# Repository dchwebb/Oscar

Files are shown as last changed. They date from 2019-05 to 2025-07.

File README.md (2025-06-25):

# Oscar

Overview
--------

Oscar is a three channel oscilloscope, tuner, spectrum analyser and MIDI event viewer designed for use in a Eurorack modular synthesiser.

- [Manual](Oscar_Manual.md)

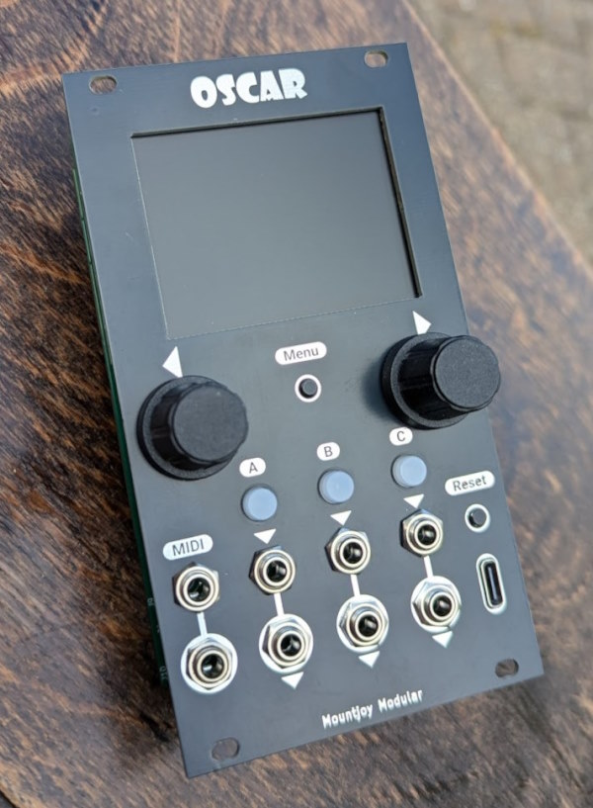
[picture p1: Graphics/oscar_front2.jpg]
Oscar icon


Version 3 changes: 
- Optimised for DIY building
    - [Build Guide](Oscar_Build_Guide.md)
    - [Bill of Materials](BOM.md)
- Illuminated buttons for quick channel selection
- USB input for firmware updates and USB MIDI analysis
- An opto-coupler and passive mult on the serial MIDI input
- Dedicated Menu button

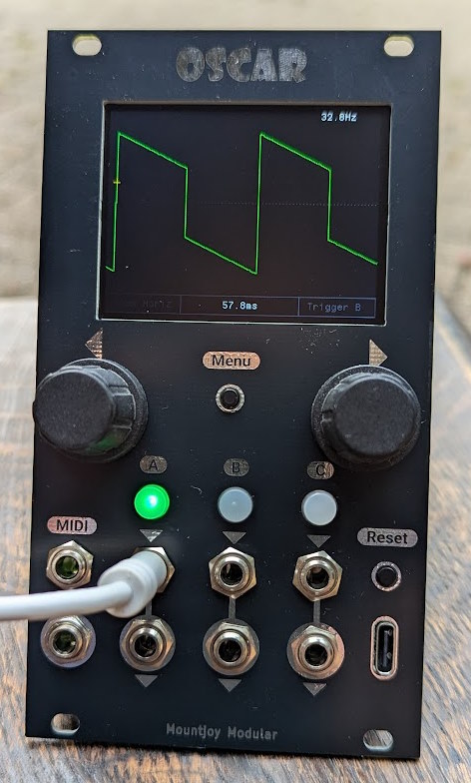
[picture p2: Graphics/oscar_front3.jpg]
Oscar icon


Functional Overview
-------------------

See [Manual](Oscar_Manual.md) for more details.

- The oscilloscope can display up to three channels at once, either in separate lanes or overlaid. Horizontal and vertical zoom are available and a trigger with adjustable x/y can be applied to any channel.

- The tuner function allows for fast and accurate tuning of audio rate signals.

- The spectrum analyser is used to show the frequency components of any signal. The frequencies of the principal harmonics are shown both graphically and numerically. An autotune function dynamically adjusts the sample rate to lock on the fundamental frequency of the signal. This gives an extremely clear view of the frequency spectrum whilst being fast enough for real-time use.

- The waterfall plot shows the frequency spectrum over time in a 3 dimensional view.

- The MIDI event viewer displays the MIDI channel, note on/off status, pitchbends, control changes and aftertouch. Clock speed is indicated with a flashing dot. 

Technical
---------

Oscar uses an SMT32F446 microcontroller to capture incoming signals with the internal ADC and display the results on a 320x240 LCD display via SPI. Code is written in C++ 20 using the STM32CubeIDE Eclipse-based IDE. Hardware interfacing is carried out through custom code (ie no STM HAL libraries).

- [Schematics](Hardware_v3/Oscar_Components.pdf)

The microcontroller is clocked at 180MHz via an external 8MHz crystal oscillator. The analog inputs are scaled with an MCP6004 op-amp and the mult outputs buffered with a TL074 op-amp. The internal UART is used to capture serial MIDI data for display via a H11L1 optocoupler (to reduce the risk of ground hum).

The display is a 320x240 TFT LCD controlled with an ILI9341 driver. Screen refreshes are sent using SPI via DMA from the microcontroller. A USB C socket functions in USB 2.0 mode with an RCLAMP0502B providing ESD protection.

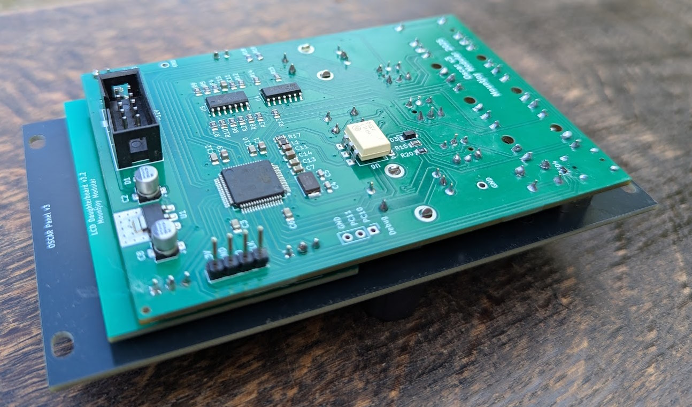
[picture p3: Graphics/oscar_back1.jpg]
Oscar icon


Analog signal capture is carried out via the internal 12 bit ADCs. Capture is controlled by a timer that is adjusted to the desired horizontal display frequency in oscilloscope mode. In Spectrum Analyser mode the autotune function dynamically alters the sampling rate to attempt to capture an integer multiple of the fundamental frequency of the incoming signal. This is done by inspecting the side-lobes of the FFT and altering the sampling rate to minimise the offset.

The tuner mode uses an overlapping FFT technique to increase accuracy. Using this mechanism samples 1 to 1024 are placed in one buffer and samples 512 to 1536 are placed in a second buffer. FFTs are carried out on each buffer and then the phase offset between the fundamental is measured. This can then be used to calculate the pitch with much enhanced accuracy for the additional processing time.

### Power Supply

The Eurorack +/-12V rails have reverse polarity protection and filtering. The 3.3V MCU and DAC digital power supplies are provided by an LT1117-3.3 linear regulator. A common digital/analog ground plane is used.

- +12V Current Draw: 151mA
- -12V Current Draw: 6mA

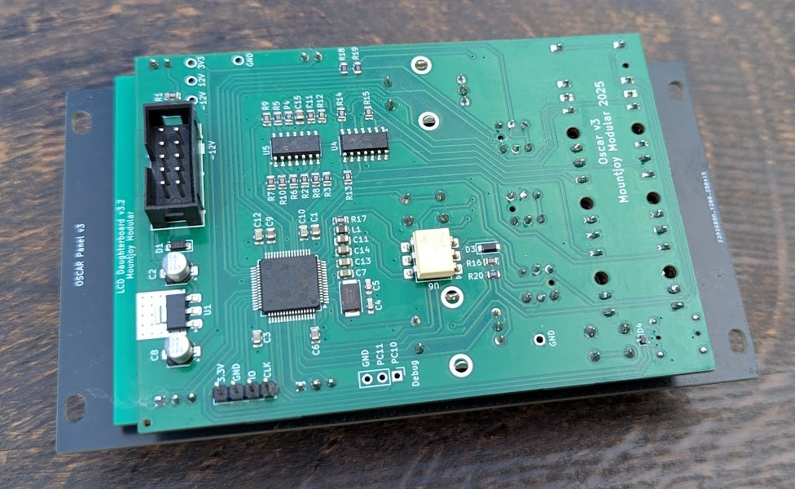
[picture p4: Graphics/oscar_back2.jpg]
Oscar icon


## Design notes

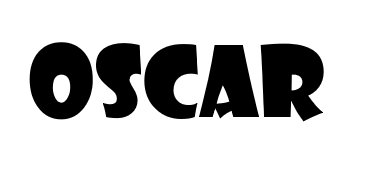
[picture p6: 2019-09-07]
Hardware_v3/Graphics/Oscar showcard gothic.png

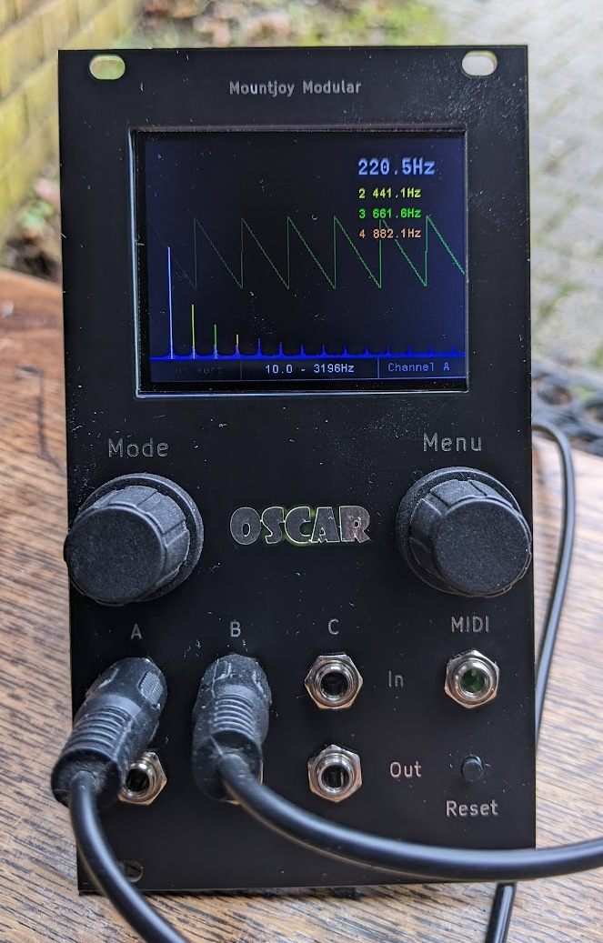
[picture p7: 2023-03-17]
Graphics/Spectrum.jpg

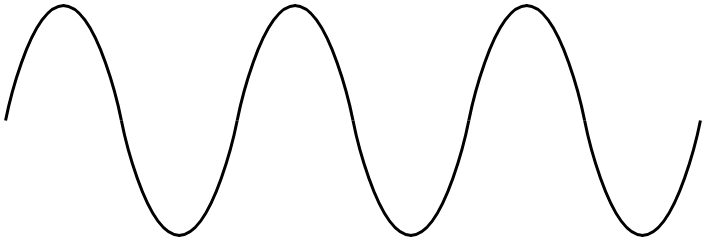
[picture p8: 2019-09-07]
Hardware_v3/Graphics/sine.png

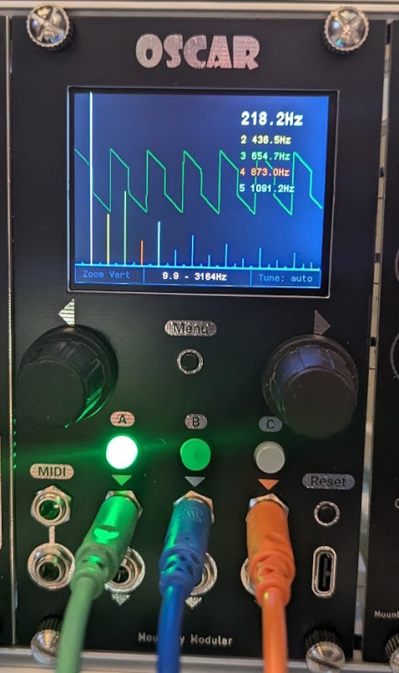
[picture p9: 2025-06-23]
Graphics/spectrum_v3.jpg

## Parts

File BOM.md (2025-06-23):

# Oscar v3 BOM

## Screen

- [2.4 inch TFT HD Color LCD Screen 2.8-3.3V 240x320 4-wire SPI interface ILI9341](https://www.ebay.co.uk/itm/394725476377)
- Various lengths of 2.54mm pin headers

## Generic Parts (optional if using JLC assembly)

|Value |Designator |Footprint |JLC |
|---|---|---|---|
|8MHz |Y1 |Crystal 5032 2 Pin 5.0x3.2mm |C115962 |
|STM32F446RETx|U3 |LQFP-64_10x10mm_P0.5mm |C69336  |
|H11L1 |U6 |H11L1 Optocoupler |C20082  |
|RCLAMP0502B  |D4 |SOT-416 ESD Protection for USB |C5370962|
|LT1117-3.3 |U1 |SOT-223-3 TabPin2 Linear Regulator |C6186 |
|TL074 |U4 |SOIC-14_3.9x8.7mm_P1.27mm OpAmp |C107644 |
|MCP6004 |U5 |SOIC-14_3.9x8.7mm_P1.27mm OpAmp |C7378 |
|1N4148W |D3 |D_SOD-123 Diode |C81598  |
|1N5819 |D1,D2 |D_SOD-123 Diode |C8598 |
|Ferrite Bead |L1 |0805 300mΩ 600Ω@100MHz Ferrite Bead |C1017 |
|22uF 16V |C2,C8 |Electrolytic Capacitor 4 x 5.8mm |C134793 |
|4.7uF |C1,C11,C15,C9 |0805 Capacitor |C1779 |
|1uF |C14 |0805 Capacitor |C28323  |
|100nF |C10,C12,C13,C3,C6,C7|0805 Capacitor |C49678  |
|30pF |C4,C5 |0603 Capacitor |C1658 |
|100 |R13,R14,R15 |0805 1% Resistor |C17408  |
|150 |R1 |0805 1% Resistor |C17471  |
|220 |R16 |0805 1% Resistor |C17557  |
|470 |R17 |0805 1% Resistor |C17710  |
|1.5k |R18,R19,R20 |0805 1% Resistor |C4310 |
|10k |R11,R12 |0805 1% Resistor |C17414  |
|15k |R10,R8,R9 |0805 1% Resistor |C17475  |
|100k |R2,R3,R4,R5,R6,R7 |0805 1% Resistor |C149504 |

## Digikey/Mouser Components

|Comment |Designator |Footprint |Digikey |Mouser |
|---|---|---|---|---|
|Menu Button  |SW2 |Tactile Switch SKHHDTA010 |4809-SKHHDTA010-ND |688-SKHHDT |
|Reset Button |SW1 |Tactile Switch SKHHDTA010 |4809-SKHHDTA010-ND |688-SKHHDT |
|Right Encoder|SW4 |Rotary Encoder PEC11R-4220F-S0024 |PEC11R-4220F-S0024-ND |652-PEC11R-4220F-S24|
|Left Encoder |SW3 |Rotary Encoder PEC11R-4220F-S0024 |PEC11R-4220F-S0024-ND |652-PEC11R-4220F-S24|
|USB C Socket |J11 |Amphenol 12401951E412A |664-12401951E412ATR-ND|523-12401951E412A |
|Eurorack 10 pin power|J2 |Eurorack 10 pin shrouded header |SAM10831-ND |200-TST10501TD |

## Thonk Components

|Comment |Designator |Footprint |Thonk |
|---|---|---|---|
|ChA Btn |BTN1 |Low Profile LED Button |[Low-Profile LED Button - GREEN](https://www.thonk.co.uk/shop/low-profile-led-buttons/)|
|ChB Btn |BTN2 |Low Profile LED Button |[Low-Profile LED Button - BLUE](https://www.thonk.co.uk/shop/low-profile-led-buttons/)|
|ChC Btn |BTN3 |Low Profile LED Button |[Low-Profile LED Button - ORANGE](https://www.thonk.co.uk/shop/low-profile-led-buttons/)|
|ChannelA In  |J4 |THONKICONN hole |[Thonkiconn Mono 3.5mm Audio Jacks (WQP518MA)](https://www.thonk.co.uk/shop/thonkiconn/)|
|ChannelB In  |J5 |THONKICONN hole |[Thonkiconn Mono 3.5mm Audio Jacks (WQP518MA)](https://www.thonk.co.uk/shop/thonkiconn/)|
|ChA Buff Out |J7 |THONKICONN hole |[Thonkiconn Mono 3.5mm Audio Jacks (WQP518MA)](https://www.thonk.co.uk/shop/thonkiconn/)|
|ChB Buff Out |J8 |THONKICONN hole |[Thonkiconn Mono 3.5mm Audio Jacks (WQP518MA)](https://www.thonk.co.uk/shop/thonkiconn/)|
|ChC Buff Out |J6 |THONKICONN hole |[Thonkiconn Mono 3.5mm Audio Jacks (WQP518MA)](https://www.thonk.co.uk/shop/thonkiconn/)|
|ChannelC In  |J3 |THONKICONN hole |[Thonkiconn Mono 3.5mm Audio Jacks (WQP518MA)](https://www.thonk.co.uk/shop/thonkiconn/)|
|MIDI IN |J9 |Thonkiconn Stereo-PJ366ST |[Green Thonkiconn Stereo 3.5mm Audio Jacks (PJ366ST)](https://www.thonk.co.uk/shop/thonkiconn/)|
|MIDI THROUGH |J10 |Thonkiconn Stereo-PJ366ST |[Green Thonkiconn Stereo 3.5mm Audio Jacks (PJ366ST)](https://www.thonk.co.uk/shop/thonkiconn/)|

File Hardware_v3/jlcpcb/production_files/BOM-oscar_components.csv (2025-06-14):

Comment | Designator | Footprint | LCSC
L | L1 | R_0805_2012Metric | C1017
TL074 | U4 | SOIC-14_3.9x8.7mm_P1.27mm | C107644
8MHz | Y1 | Crystal_SMD_5032-2Pin_5.0x3.2mm_Large_Pads | C115962
22uF | C2,C8 | CP_Elec_4x5.8 | C134793
100k | R2,R3,R4,R5,R6,R7 | R_0805_2012Metric | C149504
30pF | C4,C5 | C_0603_1608Metric_Pad1.08x0.95mm_HandSolder | C1658
100 | R13,R14,R15 | R_0805_2012Metric | C17408
10k | R11,R12 | R_0805_2012Metric | C17414
150 | R1 | R_0805_2012Metric | C17471
15k | R10,R8,R9 | R_0805_2012Metric | C17475
220 | R16 | R_0805_2012Metric | C17557
470 | R17 | R_0805_2012Metric | C17710
4.7uF | C1,C11,C15,C9 | C_0805_2012Metric | C1779
H11L1 | U6 | H11L1 | C20082
1uF | C14 | C_0805_2012Metric | C28323
1.5k | R18,R19,R20 | R_0805_2012Metric | C4310
100nF | C10,C12,C13,C3,C6,C7 | C_0805_2012Metric | C49678
RCLAMP0502B | D4 | SOT-416 | C5370962
LT1117-3.3 | U1 | SOT-223-3_TabPin2 | C6186
STM32F446RETx | U3 | LQFP-64_10x10mm_P0.5mm | C69336
MCP6004 | U5 | SOIC-14_3.9x8.7mm_P1.27mm | C7378
1N4148W | D3 | D_SOD-123 | C81598
1N5819 | D1,D2 | D_SOD-123 | C8598
Menu_Button | SW2 | SW_PUSH_6mm_aligned
ILI9341_SPI_Daughterboard | U2 | ILI9341_SPI_daughterboard_v2
ChannelA_In | J4 | THONKICONN_hole
ChannelB_In | J5 | THONKICONN_hole
ChA_Buff_Out | J7 | THONKICONN_hole
ChB_Buff_Out | J8 | THONKICONN_hole
ChC_Buff_Out | J6 | THONKICONN_hole
Right_Encoder | SW4 | Encoder
Left_Encoder | SW3 | Encoder
ChannelC_In | J3 | THONKICONN_hole
MIDI_IN | J9 | Thonkiconn_Stereo-PJ366ST
Reset_Button | SW1 | SW_PUSH_6mm_aligned
ChB_Btn | BTN2 | Low_Profile_LED_Button
ChC_Btn | BTN3 | Low_Profile_LED_Button
ChA_Btn | BTN1 | Low_Profile_LED_Button
USB_C_Receptacle | J11 | USB_C_Receptacle_Amphenol_12401951E412A
MIDI_THROUGH | J10 | Thonkiconn_Stereo-PJ366ST

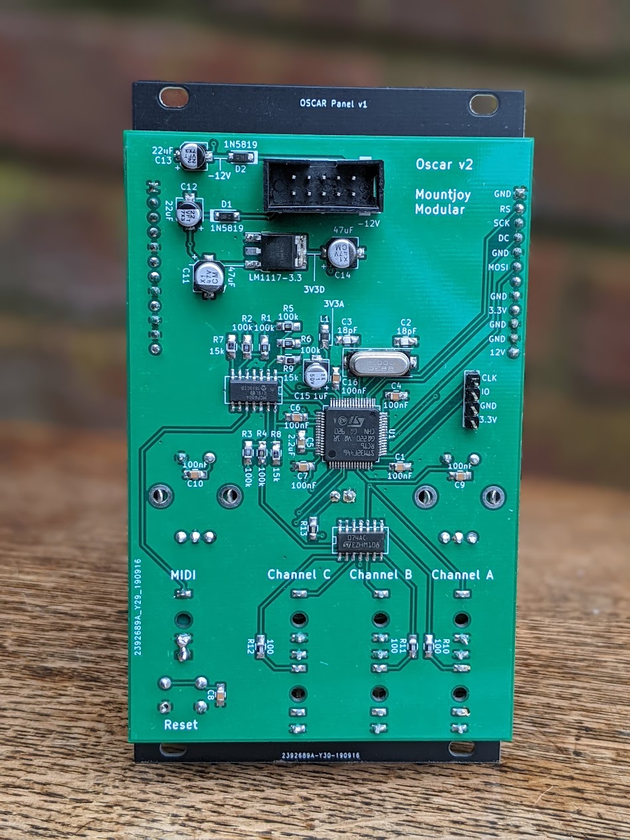
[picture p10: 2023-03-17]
Graphics/Components.jpg

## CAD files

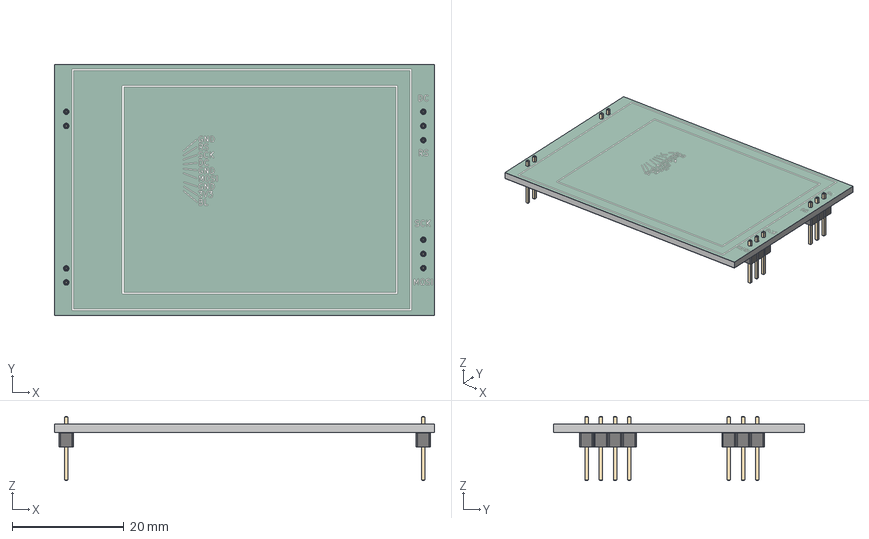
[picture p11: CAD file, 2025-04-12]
Hardware_v3/lcd_Daughterboard.step
68.0 x 45.0 x 11.5 mm
PinHeader_1x02_P2.54mm_Vertical x 2
PinHeader_1x03_P2.54mm_Vertical x 2
lcd_Daughterboard_copper
lcd_Daughterboard_silkscreen
lcd_Daughterboard_soldermask
lcd_Daughterboard_PCB

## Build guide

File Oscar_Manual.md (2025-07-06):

# Oscar Manual

## Table of Contents

- [Oscar Manual](#oscar-manual)
   * [Table of Contents](#table-of-contents)
   * [Introduction](#introduction)
   * [Basic Navigation](#basic-navigation)
   * [Functions](#functions)
      + [Oscilloscope](#oscilloscope)
      + [Tuner](#tuner)
      + [Spectrum Analyser](#spectrum-analyser)
      + [Waterfall Plot](#waterfall-plot)
      + [MIDI Analyser](#midi-analyser)
   * [Firmware Upgrade](#firmware-upgrade)

## Introduction

Oscar is a multi-function Eurorack module, combining oscilloscope, tuner, spectrum analyser, waterfall display and MIDI analyser.

It combines three channels each of which has an input selector button, input and buffered mult output. The MIDI analyser accepts a single serial MIDI input on 1/8" jack with unbuffered multiple. 

A USB socket allows analysis of USB MIDI data, firmware updates and a serial console with access to system configuration.

## Basic Navigation

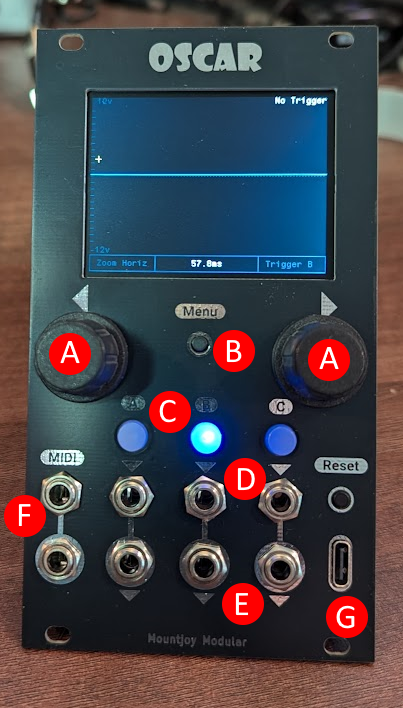
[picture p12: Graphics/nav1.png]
Navigation icon


**A)** Pressing the rotary encoders cycles through the different modes:

Oscilloscope -> Tuner -> Spectrum analyser -> Waterfall plot -> MIDI Analyser

Turning the encoders changes the parameters shown at the bottom left and right of the screen.

**B)** The rotary controllers also change the parameters shown on the bottom corners of the screen. Use the Menu button to choose which parameters are controllable on each encoder (these options vary according to mode).

**C)** The A, B and C buttons activate channels. In oscilloscope mode multiple channels may be selected. Otherwise a button just selects a single channel.

**D)** Inputs for channels A, B and C

**E)** Buffered multiples of the input channels

**F)** Serial MIDI input and unbuffered multiple (using the MIDI standard of Tip = Sink (Data), Ring = Source (5V) and Sleeve = Shield).

**G)** Reset button and USB C MIDI In

## Functions

### Oscilloscope

The oscilloscope can display up to 3 channels, either in separate lanes or overlaid.

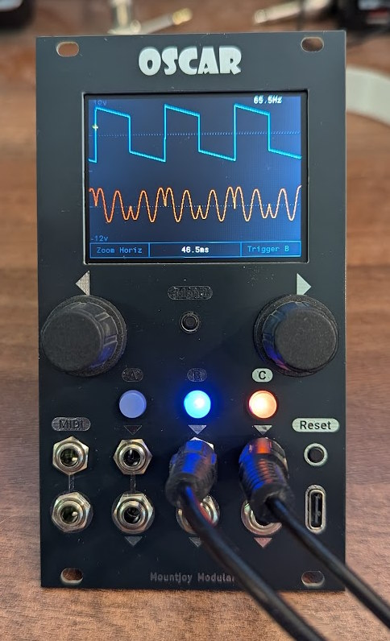
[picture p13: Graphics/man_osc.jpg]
Oscilloscope icon


At the top right a frequency estimate is shown of the currently captured signal and at the bottom center the width of the display is shown in milliseconds.

A triggering system will align the display to the trigger point, shown by a yellow cross. If the signal has not crossed the trigger point after a second the screen will update and wait for the next trigger.

Pressing the Menu button allows different parameters to be assigned to the rotary encoders.

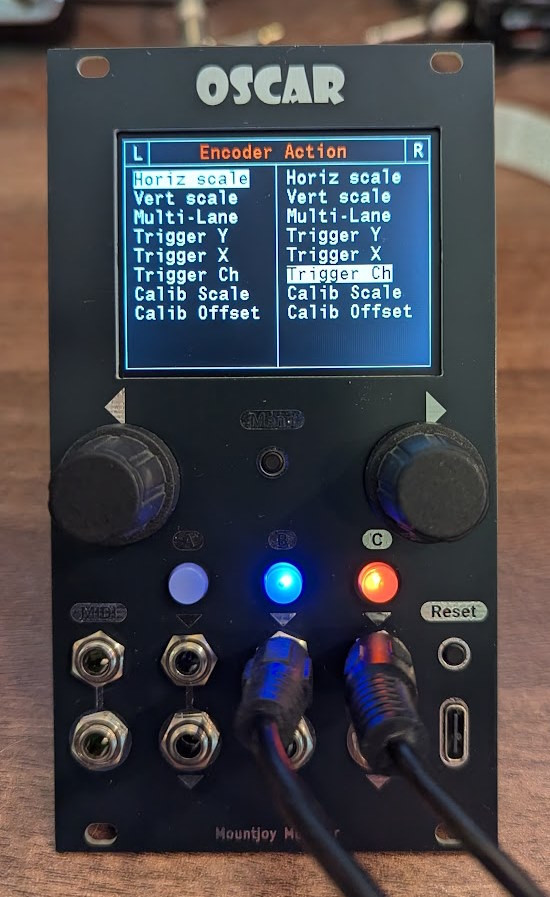
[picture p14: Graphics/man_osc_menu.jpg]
Oscilloscope Menu icon


The following parameters can be assigned to the rotary encoders:

- **Horiz scale** Zooms the display horizontally from 0.7ms at the fastest time to 700ms at the slowest.

- **Vert scale** Zooms the display vertically from 1 volt to 12 volts peak to peak.

- **Multi-Lane** Selects whether multiple channels are overlaid or shown in separate lanes.

- **Trigger Y** Sets the vertical trigger position.

- **Trigger X** Sets the horizontal trigger position.

- **Trigger Ch** Selects which channel the trigger is active on (or no trigger to disable). Note that only a visible channel can be triggered on.

- **Calib Scale** Allows calibration of the vertical scale - feed in a signal of known amplitude and set so that the volt scale matches.

- **Calib Offset** Use to calibrate the zero volt position.

### Tuner

The tuner is used to tune audio rate signals. When a valid signal is received the tuner displays the musical note and the number of cents above or below concert pitch. Below is shown the Hertz measurement and an overlay of the captured signal.

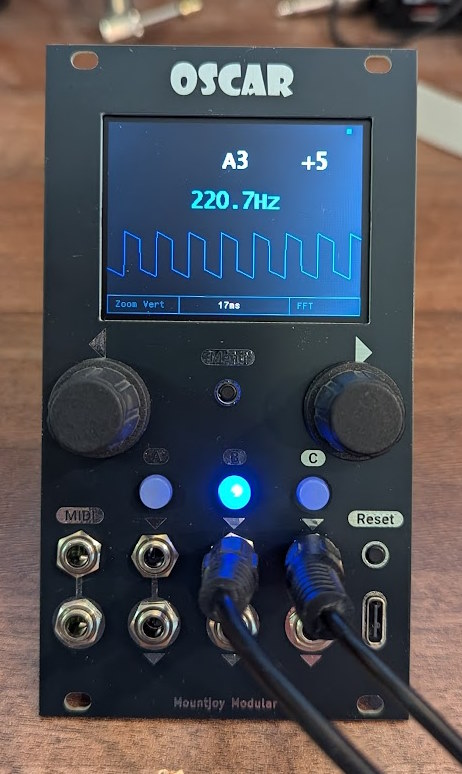
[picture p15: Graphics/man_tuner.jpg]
Tuner icon


A flashing dot at the top right of the screen changes each time a signal is captured and measured. The measurement time is shown in milliseconds at the bottom.

The rotary encoders provide the following options:

- **Vert scale** Zooms the wave overlay display vertically.

- **Tuner Mode** Two tuner modes are available. FFT is the most accurate but can be slightly slower. Zero Crossing mode checks for zero crossings in the signal which can be confused by complex waveforms, but is slightly faster in some cases.

- **Trace Overlay** Chooses whether the waveform is overlaid at the bottom of the screen.

### Spectrum Analyser

The Spectrum Analyser mode is used to display the harmonic content of a signal. The fundamental frequency is shown as a white bar whose height indicates the strength of the harmonic.

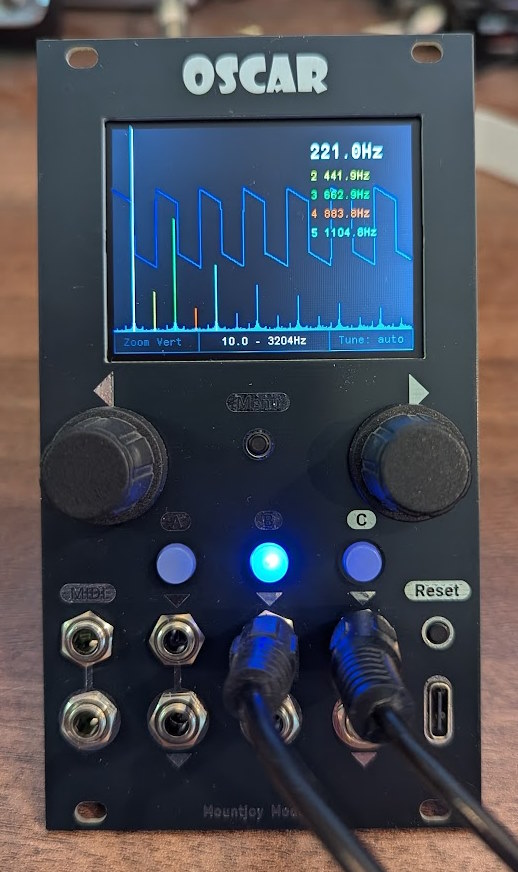
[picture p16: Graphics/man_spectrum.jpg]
Spectrum Analyser icon


Additional harmonics are displayed as coloured bars, with the frequencies of the first five harmonics shown on the right of the display.

The captured waveform can be optionally overlaid on the screen and the frequency analysis range is displayed at the bottom.

Encoder parameters:

- **Vert scale** Zooms the wave overlay display vertically.

- **Auto Tune** The accuracy of an FFT analysis is affected by the sampling rate. The Auto tune mechanism used here attempts to adjust the sampling rate to an exact multiple of the signal for an accurate analysis. This can be disabled, usually to cope with very complex signals, but the accuracy of the frequency measurements will be adversely affected.

- **Horiz scale** If auto tune is disabled this alters the sampling rate to adjust the frequency of the spectrum being captured.

- **Trace overlay** Chooses whether the waveform is overlaid.

### Waterfall Plot

This mode displays the frequency spectrum of the signal as it changes over time. The only encoder action is to adjust the sampling frequency which affects which frequency ranges are displayed (shown at the bottom of the screen).

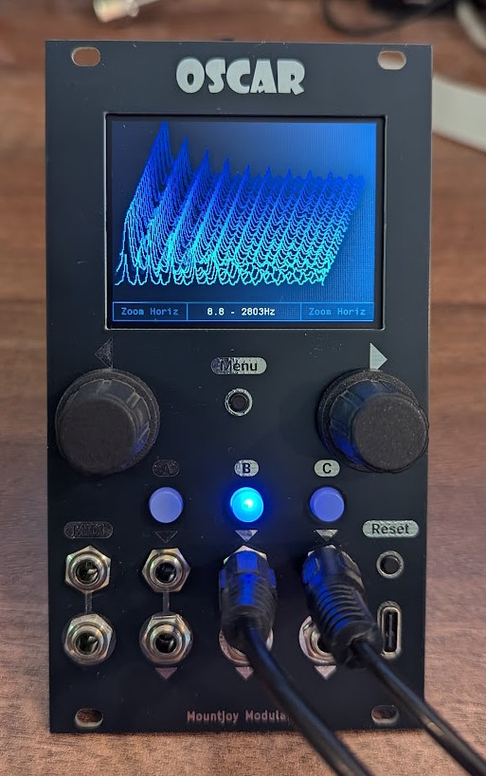
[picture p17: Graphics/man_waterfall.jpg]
Waterfall icon


Note that altering the sampling frequency will change the time it takes to capture the samples to display so very low sampling rates will cause the screen refresh rate to fall.

### MIDI Analyser

Both serial and USB MIDI data can be displayed simultaneously. The display will show note on/off events, control changes, aftertouch and pitchbends. The MIDI clock rate is indicated by a flashing dot at the bottom right for serial MIDI and bottom left for USB. Sysex data is not shown.

Different colours are used to indicate the MIDI channel for each type of event displayed (also the number is shown in the far left column.

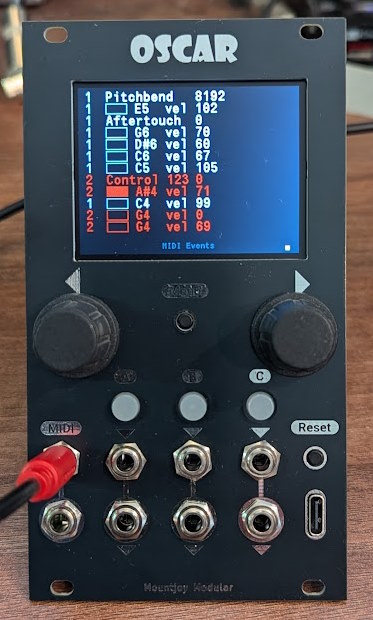
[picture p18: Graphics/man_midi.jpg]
MIDI icon


Serial MIDI input uses a 1/8" jack socket wired to the current MIDI standard, and is protected by an opto-coupler. The two serial sockets are wired as direct mults with no buffering.

USB MIDI is received on a USB-C socket. The module can only act as a USB device so is not suitable for analysing MIDI USB data from keyboards etc.

## Firmware Upgrade

A mechanism is provided to upgrade the firmware over USB. Note that the latest firmware for the module can be found here: [Oscar_v3.elf](Oscar_v3/Debug). Download the file (use raw format to get the file in binary format).

Connect a serial console application to the USB serial port:

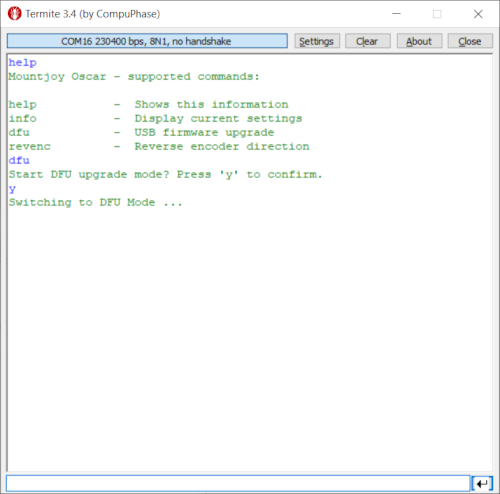
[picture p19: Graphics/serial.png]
Serial Console icon


In the serial console type **dfu**. This will reboot the module into DFU (Device Firmware Upgrade) mode.

Run the STM Cube Programmer software available here: [STM Cube Programmer](https://www.st.com/en/development-tools/stm32cubeprog.html).

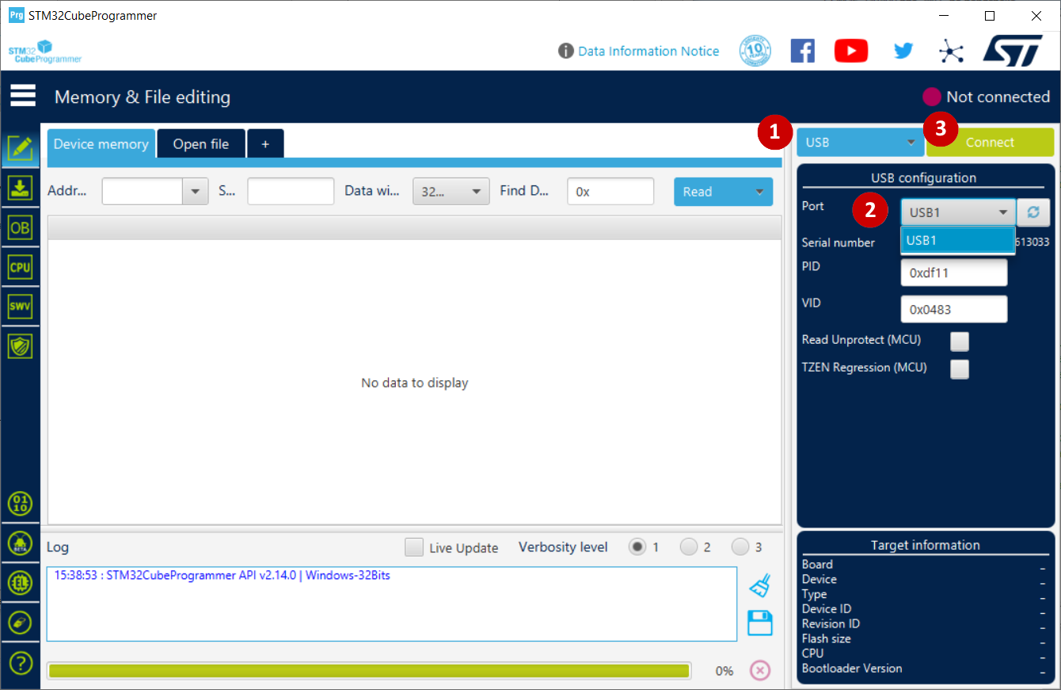
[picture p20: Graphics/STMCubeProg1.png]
Programmer


1. Select USB connection
2. Click Refresh and select the appropriate USB port (USB1 here)
3. Click Connect

<br />
<br />

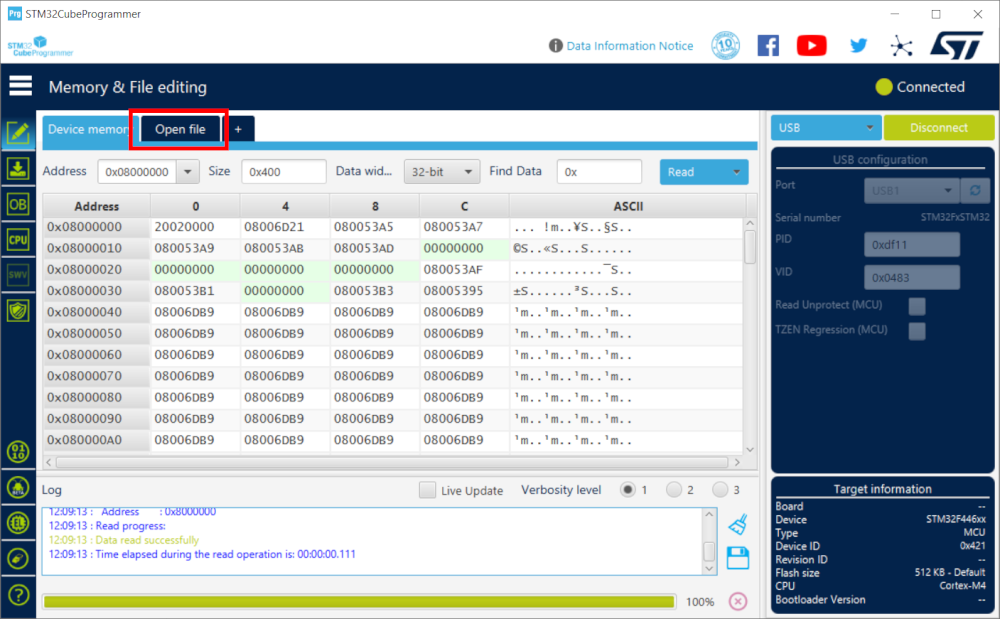
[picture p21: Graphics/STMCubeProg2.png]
Programmer2


- Click 'Open file' and navigate to the Oscar_v3.elf firmware file downloaded from the [Firmware Repository](Oscar_v3/Debug).

<br />
<br />

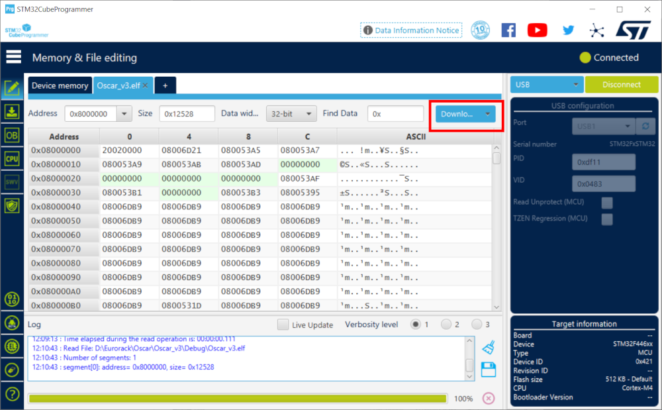
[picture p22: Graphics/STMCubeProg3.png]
Programmer3


- Click the 'Download' button to transfer the firmware onto Oscar.
- Restart the module. Note you can use the console command **info** to view the firmware build date to confirm an upgrade has succeeded.

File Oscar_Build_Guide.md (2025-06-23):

# Oscar Build Guide

## Table of Contents

## Introduction

Oscar v3 has been optimised as far as possible for DIY building. All surface-mount components (with the exception of the USB socket) can be assembled using JLC PCB's assembly service.

The module is constructed of 3 PCBs: 

- Component and control PCB: a four-layer PCB with surface-mount components on the back and the through-hole controls on the front.

- LCD daughterboard: this is used to raise the LCD display to the level of the front panel. The LCD panel's flexable PCB is soldered to the daughterboard which is then attached to the component PCB in four corners.

- Panel: There are two variants - one where USB-C is not needed. See the [USB Socket](#usb-socket) section for details.

As the module is based around an STM32 microcontroller you will need an ST-Link programmer (or clone, available on e-bay for under $10).

These are the three PCBs, one partly assembled by JLC PCB, the LCD screen and the ST-Link Programmer:

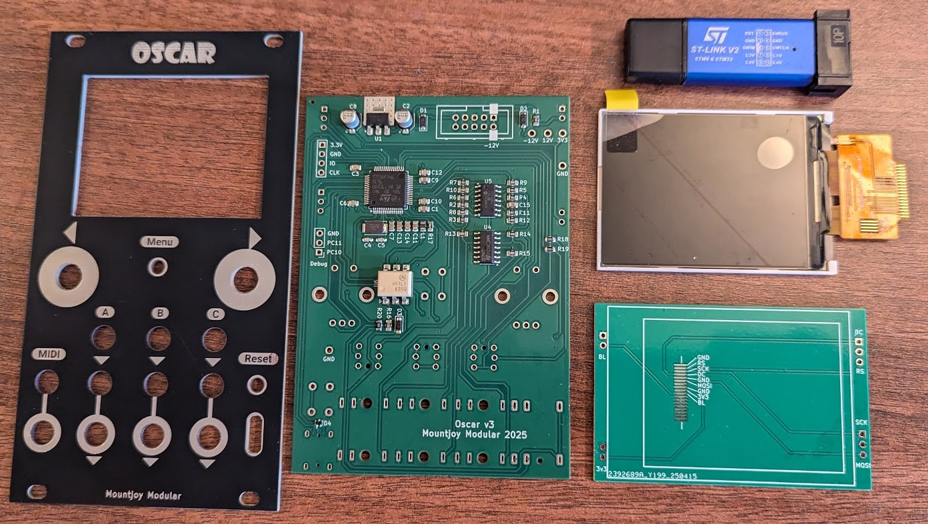
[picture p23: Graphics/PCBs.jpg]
PCBs, LCD and programmer


## Bill of Materials (BOM)

The BOM lists the various suppliers and part numbers that are needed to build Oscar.

- [Bill of Materials](BOM.md)

These are the through-hole controls needed in addition to the surface mount components:

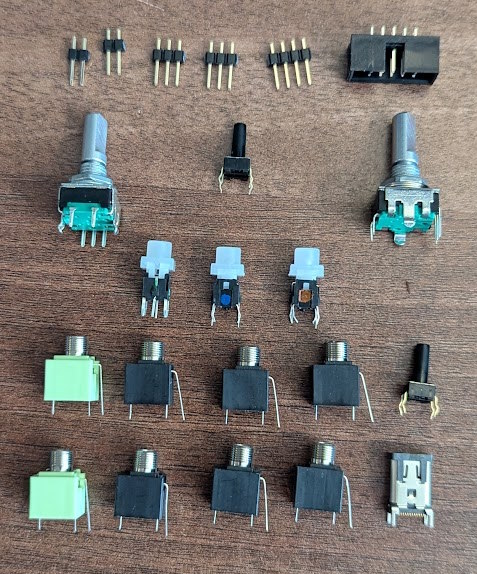
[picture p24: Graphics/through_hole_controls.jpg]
Through-hole Controls


## PCB Ordering and Assembly

The gerber files and JLC PCB assembly files are available here (use the latest versions where multiple available):

- [Panel and Daughterboard Gerbers](Hardware_v3/Gerbers)
- [Component PCB gerbers and production files](Hardware_v3/jlcpcb/production_files)

If using JLC to assemble the surface-mount components select the 'Assemble bottom side' option. Note that 2 assembled boards is the minimum that can be selected.

It is recommended to use the 'Lead free HASL' process on the panel to avoid the risk of touching a lead metal finish when operating the module (though it adds $1.20 to the cost). Select 'Black' as PCB colour.

At June 2025 the JLC costings with full SMD assembly are:

- Component board, parts and assembly (5 PCBs, 2 assembled): $48.94
- Panel (5 PCBs): $8.70
- Daughter board (5 PCBs): $2.00

JLC support two types of component: 'Basic' and 'Extended'. If you are happy hand-soldering surface-mount components you can exclude some or all of the extended parts to reduce costs (each extended part has a surcharge of $3). The cost of the assembled boards can be reduced to $30.59 by excluding all extended parts except the microcontroller.

These figures are exclusive of sales tax and shipping.

## Component PCB initial assembly

Whether you are hand-soldering the surface-mount parts or using JLC assembly it is recommended to carry out some basic testing at this stage of the build.

### Power testing

Firstly check for shorts on the power rails using a multimeter in resistance mode using the test points at the top right of the PCB. 

The resistance from the +12V and -12V to ground should be in the kilo-ohm range (and will change as capacitors charge). The resistance from the 3.3V rail to ground should be around 300ohm.
 
Solder on the 10 pin Eurorack connector and connect to a Eurorack power supply. Test the 3 voltage rails using a multimeter in DC volt mode. Note that the 12 volt rails will measure slightly low owing the drop in the reverse polarity protection diodes.

### Microcontroller

It is also recommended to check that the STM32 microcontroller is working. Solder on the programming header (marked '3.3V, GND, IO, CLK' at the top left) using a 4 way 2.54mm pin header.

Connect an ST-Link Programmer to the programming header. There are 10 connections on the ST-Link v2 programmer but you only need to connect GND to GND, SWDIO to IO, SWCLK to CLK. Use the 3.3v connection from the programmer if you are not powering from a Eurorack power supply.

Run the STM Cube Programmer software (available here: [STM Cube Programmer](https://www.st.com/en/development-tools/stm32cubeprog.html)).

1. Ensure that ST-LINK is selected at the top right and click 'Connect'

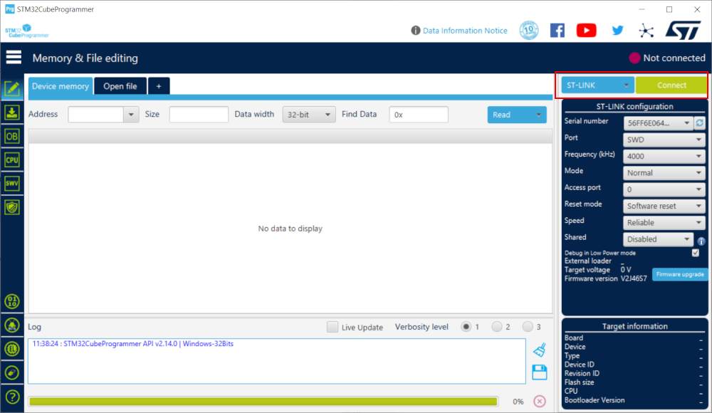
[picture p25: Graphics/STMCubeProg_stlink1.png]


2. Check that the target information in the bottom right is correct - this means that the programmer has found the microcontroller and that it is functional.

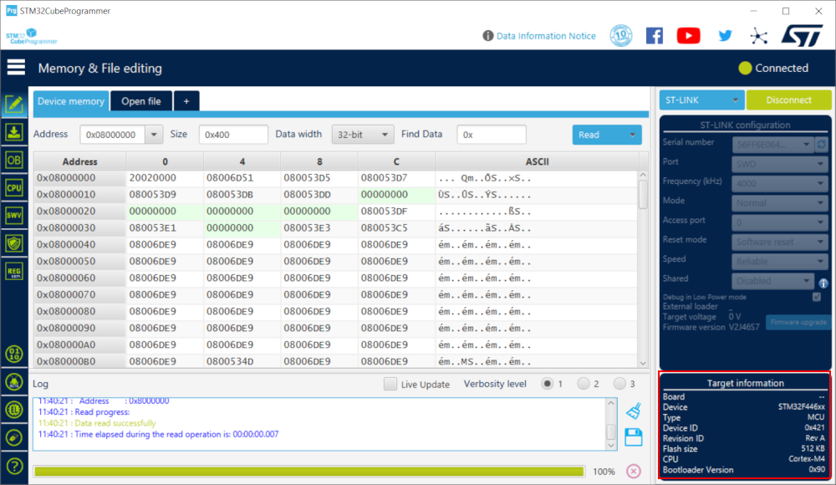
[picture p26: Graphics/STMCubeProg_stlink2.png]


3. Click 'Open File' (top left) and navigate to the Oscar_v3.elf firmware file downloaded from Github and then click the 'Download' button (to the top right).

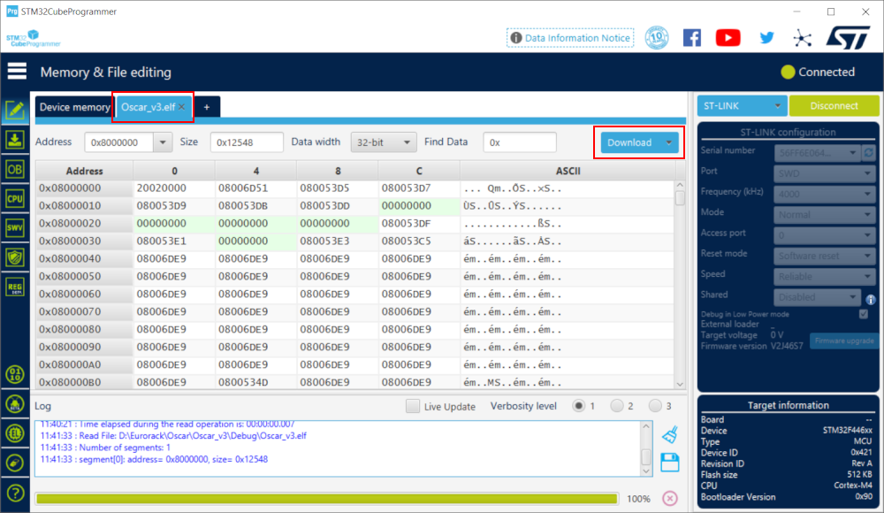
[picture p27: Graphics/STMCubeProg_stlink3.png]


If all goes well the microcontroller will be working and loaded with the current firmware.

## USB socket

The optional USB socket should be installed next (if required) as you cannot reach the pins once the jack sockets are installed.

The USB-C socket is one of the hardest components to hand-solder as the pins are very small and the through-hole legs get in the way of some of the pins.

The USB socket is used to carry out firmware updates over USB (easier than using the ST-Link programmer), for analysing USB MIDI data and to provide a serial console for some basic configuration and diagnostics. None of these functions are critical so the installation of the socket is optional. If you are not installing the socket then a variant panel is available with the USB socket hole covered.

My preferred soldering technique is to first apply a small amount of solder to the pads. I then apply flux and position the socket.

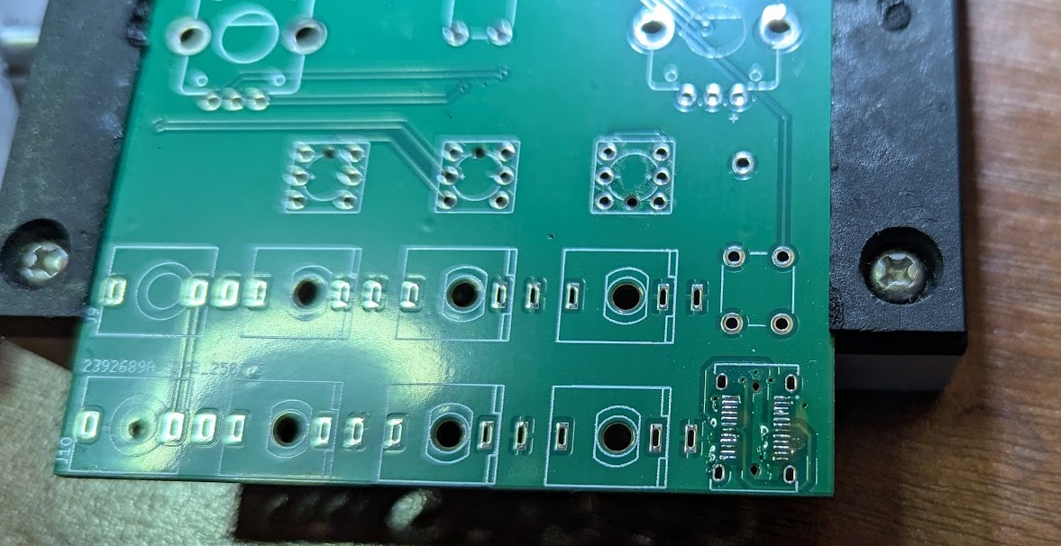
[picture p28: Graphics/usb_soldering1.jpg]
Prepare PCB


Using a small bevelled soldering iron tip (eg Hakko T18-CF15) tack down a couple of the USB socket pins to one side. check the alignment of the pins on the other side and then tack that side down too. Once the socket is secured by a couple of pins on each side I go round soldering the more awkward corner pins.

I find angling the PCB while applying the solder helps see where the tip of the soldering iron needs to go. Note that the majority of the pins on the socket are unused, but the four corner pins are the ground connections which are important (and the most difficult to reach).

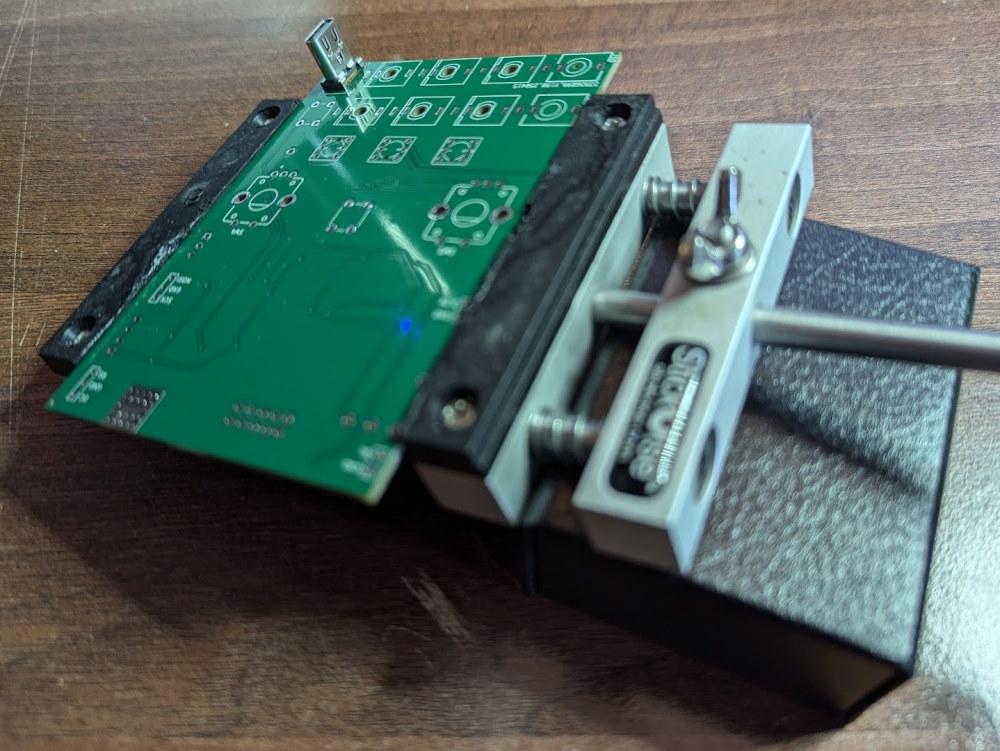
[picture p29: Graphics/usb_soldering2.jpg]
Solder Socket


Once all the pins are secured then the four through-hole legs can be soldered to the PCB for mechanical strength.

To test, connect the USB socket to a computer and apply power to the Eurorack power connector. If you have correctly installed the firmware and the USB socket is working the device should show up as a MIDI and serial USB device. In Windows:

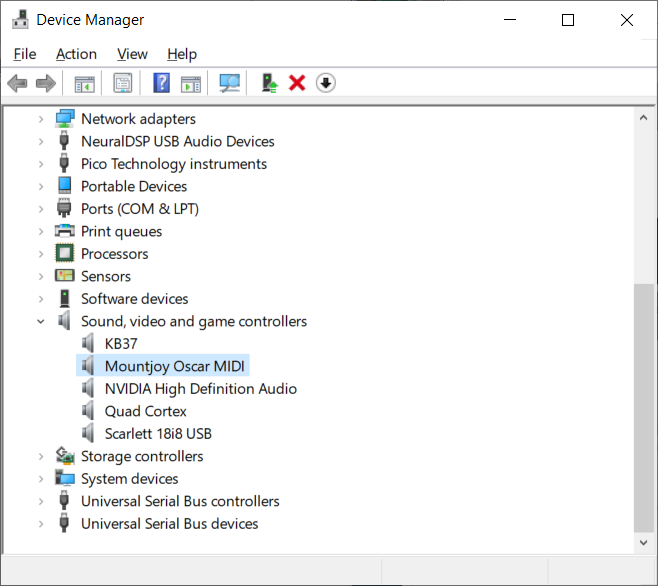
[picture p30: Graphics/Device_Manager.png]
Device Manager


## Additional Controls

The remaining through-hole components can now be soldered to the Component PCB. First place them in their holes.

*Important* The through hole controls are mounted on the opposite side of the PCB to the surface-mount components:

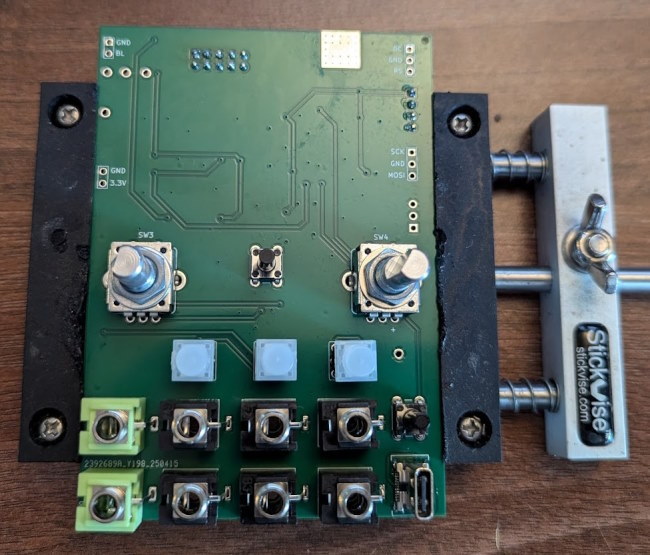
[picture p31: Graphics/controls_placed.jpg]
Controls Placed


Ensure that the three illuminated buttons are rotated so the notch in the PCB matches the peg on the underside of the button. The LEDs will not work if the buttons are reversed. The colour order of the buttons is Green, Blue, Orange as you look from the panel side of the module.

Note that the rotary encoders are not high enough to properly support the panel. I used a couple of washers and a nut to achieve the correct height.

Then attach the panel to ensure correct alignment and secure with a nut and an elastic band. Turn the board over and solder the controls in place.

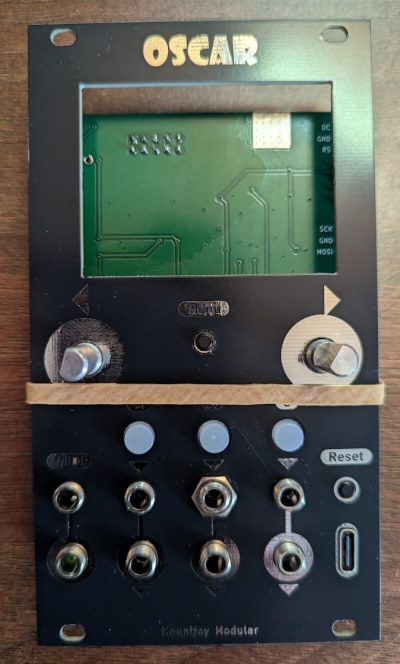
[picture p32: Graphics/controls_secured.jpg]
Controls Secured


## LCD Daughterboard

There appear to be a couple of variants of the LCD available. Look on Ebay (or elsewhere) for '2.4 inch TFT HD Color LCD Screen 2.8-3.3V 240x320 4-wire SPI interface ILI9341'. This is the one in the ebay listing, but the one they sent looks a bit different:

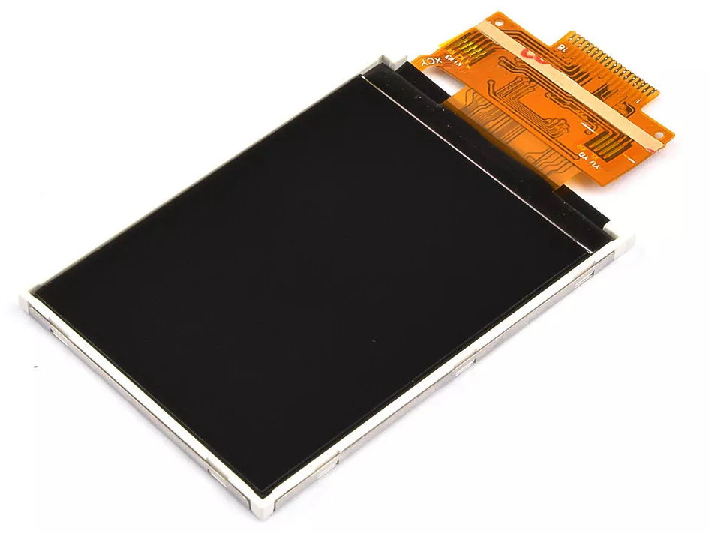
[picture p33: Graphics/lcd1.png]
LCD Front

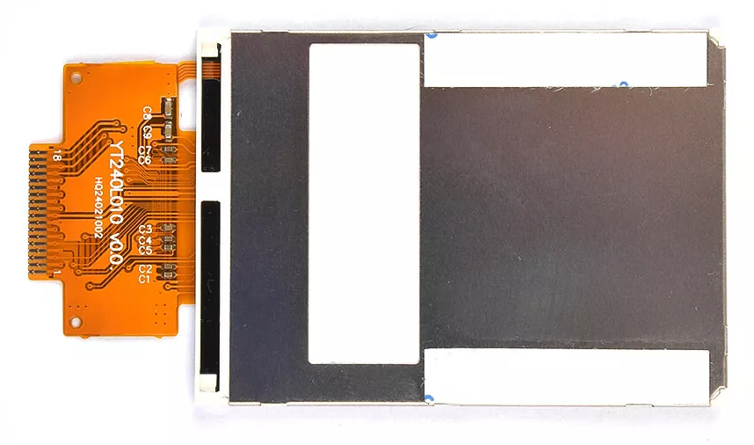
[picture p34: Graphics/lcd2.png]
LCD Back


It is recommended to solder the 4 pin headers to the daughterboard before soldering on the LCD. 

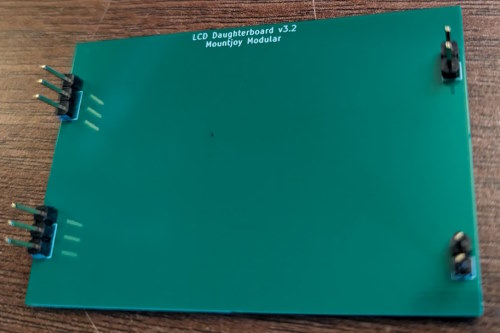
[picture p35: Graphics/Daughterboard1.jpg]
Daughterboard 1


Initially only solder one pin on each header so the angle can be tweaked to ensure the daughterboard fits cleanly into the Component PCB. Once the headers are aligned correctly solder the remaining pins.

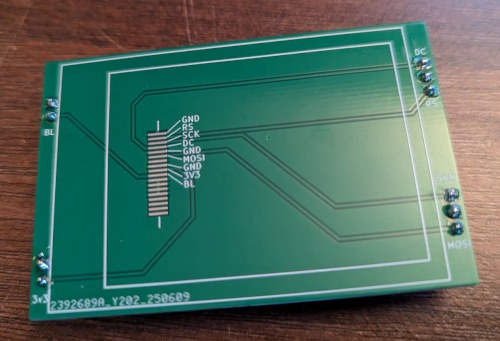
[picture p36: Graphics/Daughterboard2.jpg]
Daughterboard 2


The LCD can now be soldered to the daughterboard. There is a white line above and below the PCB pads. This indicates the location of the edge of the flex-pcb connector. Put a little solder on the pads and then solder the flex-pcb connector to the pads.

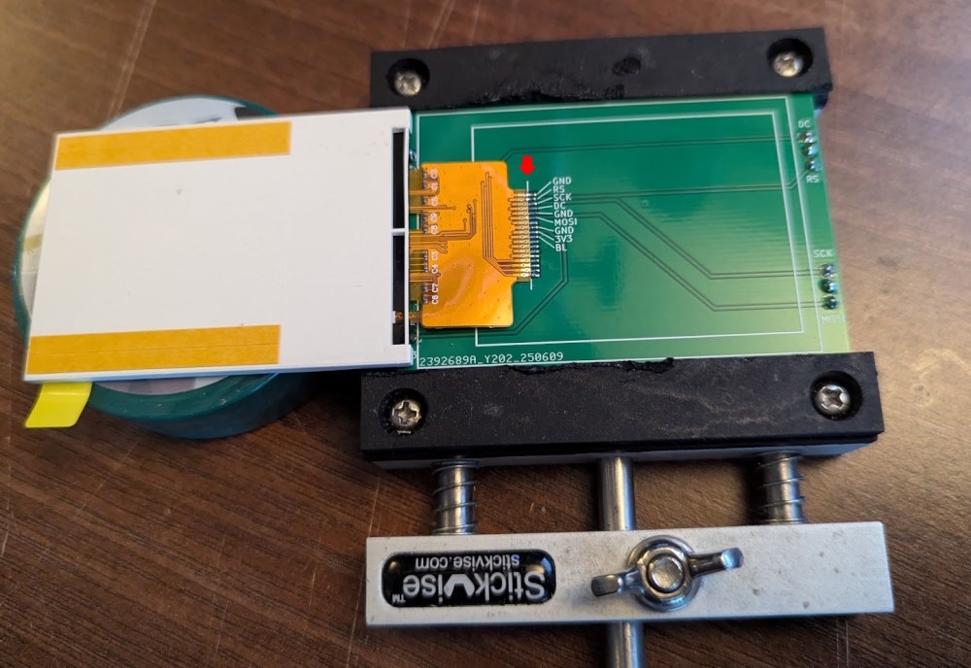
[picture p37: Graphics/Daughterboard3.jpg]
Daughterboard 3


The daughterboard should be attached to the component PCB before sticking down the LCD. Place the daughterboard in the four holes, put the panel on (and secure with a couple of nuts) and turn the assembly upside down.

Ensure the LCD is lying flat against the panel and then solder the four pin headers, applying gentle pressure to ensure the LCD is flush against the panel. Again it is recommended to only solder one pin on each header so that adjustments can be made if needed. Once the alignment looks correct solder all pins.

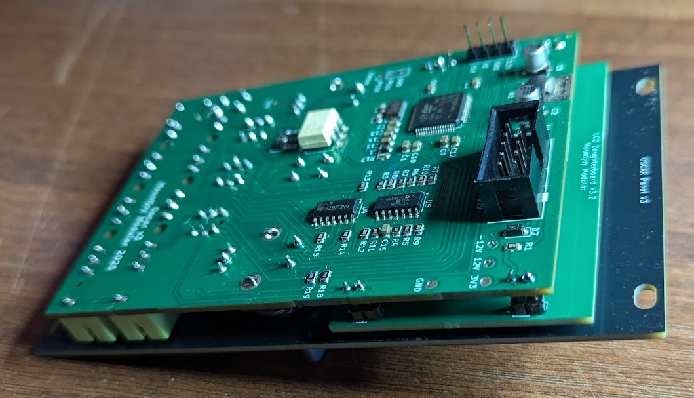
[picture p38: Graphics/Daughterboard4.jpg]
Daughterboard 4


The LCD can now be tested by applying Eurorack power (assuming you have correctly installed the firmware). If the LCD backlight comes on but there is no display check the soldering of the flex-pcb connector.

Once everything is working correctly the LCD can be aligned as accurately as possible and the stuck down with the adhesive pads on the back.

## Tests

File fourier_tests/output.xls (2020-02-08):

cnt | cnd | harmonic
1 | 1 | 0.014893
2 | 0.984375 | 0.080326
3 | 0.96875 | 0.015959
4 | 0.953125 | 0.044772
5 | 0.9375 | 0.013516
6 | 0.921875 | 0.027123
7 | 0.90625 | 0.016746
8 | 0.890625 | 0.045649
9 | 0.875 | 0.011159
10 | 0.859375 | 0.016702
11 | 0.84375 | 0.013984
12 | 0.828125 | 0.015722
13 | 0.8125 | 0.010767
14 | 0.796875 | 0.012411
15 | 0.78125 | 0.015869
16 | 0.765625 | 0.089076
17 | 0.75 | 0.007147
18 | 0.734375 | 0.010185
19 | 0.71875 | 0.0107
20 | 0.703125 | 0.010505
21 | 0.6875 | 0.00708
22 | 0.671875 | 0.008927
23 | 0.65625 | 0.013357
24 | 0.640625 | 0.018909
25 | 0.625 | 0.004319
26 | 0.609375 | 0.008228
27 | 0.59375 | 0.010965
28 | 0.578125 | 0.008906
29 | 0.5625 | 0.006944
30 | 0.546875 | 0.007911
31 | 0.53125 | 0.01465
32 | 0.515625 | 0.250122
33 | 0.5 | 0.00088
34 | 0.484375 | 0.007911
35 | 0.46875 | 0.008475
36 | 0.453125 | 0.008906
37 | 0.4375 | 0.00515
38 | 0.421875 | 0.008228
39 | 0.40625 | 0.012745
40 | 0.390625 | 0.018909
41 | 0.375 | 0.005242
42 | 0.359375 | 0.008927
43 | 0.34375 | 0.011691
44 | 0.328125 | 0.010505
45 | 0.3125 | 0.009151
46 | 0.296875 | 0.010185
47 | 0.28125 | 0.016056
48 | 0.265625 | 0.089076
49 | 0.25 | 0.00867
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

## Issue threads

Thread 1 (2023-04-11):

Ready for an amateur to build?

KeLaiFu, 2023-04-11:
This looks like a fun build and with the MCU chips finally becoming available, it looks like it won't be too difficult.
A few questions.
Is the code stable in the current build or would I need to update it later on?
and probably a stupid question...but would it be a big deal to rotate the screen 90 degrees? I can do this in kicad, but does it require a lot of work in the code too?

Thanks for sharing this great module!

dchwebb, 2023-04-11:
Hi. I am actually writing some updates to the code at present to provide a dedicated tuner function – this is nearly complete and in testing. The previous stable version is in the commit made on Mar 22, 2023. The elf file in Oscar/Oscar446/Debug/ is the firmware I am running on my stable system.

It would be a real pain to rotate the screen by 90 degrees – to get optimal performance most of the screen update code is hand crafted and works differently in the different modes. Eg in the oscilloscope mode the screen is drawn vertical line by vertical line as new samples are taken. In the Spectrum Analyser mode the screen is drawn using partial frame buffers 1/3 of the width of the screen.

Re the physical build: one problem with the original design is that I left the Boot pin floating – this should be tied to ground via a resistor or programming can be a bit iffy. I am not sure if it is obvious from the pictures but I used a custom lcd daughterboard and soldered the screen’s ribbon cable to that. This then is quite a tight fit so I had to do some fiddling to get the header to fit the space. I can send pictures if necessary.

Also for the MIDI analyser to use the MIDI standard 3.5mm cable type I had to use a stereo jack and jumper a couple of the pins together.

At some point I am going to do a hardware respin to add dedicated buttons for the different functions and provide a proper isolated MIDI input.

If you are still interested in doing a build as it stands I would be happy to send you some of the current PCBs – I have a few spares lying around here.

Dom

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

KeLaiFu, 2023-04-11:
Thanks for the update Dom,
I think for now I will wait for your newer hardware revision, I am not the fastest out of the blocks, if I started building this current version you would have revised it before I get around to finishing it. Will keep an eye on the repo though, it looks like a huge upgrade to my 0.96" screen nano powered scope...

KittenVillage, 2025-03-24:
Hi! I'm interested in this build. I see you've updated  recently. I'm confident in my build skills and can probably muddle through the flashing instructions you've left. The hardware is ready?

I'd love a pic or two of how the screen fits on. (You mentioned a ribbon cable...) and how does the daughter card work?

Any pcbs available? You can find me with this handle at gmail or modwiggler. Thx.

dchwebb, 2025-03-25:
I'm actually just about to start work on a v2. It will probably take a while, but if you want to wait then I can send you over some PCBs when the design is done. I usually get them part populated at JLC so that saves a lot of tedious SMD soldering (unless that is what you like, in which case you can have bare boards).

I also haven't decided how much to concentrate on making the design simple and DIY friendly, or use a more advanced microcontroller to enable higher speeds and more features. In the later case the design will be more complex as there will be multiple power supplies and I'll probably move to smaller 0603 parts for the majority of the passives.

Or I could do an in between design where I just refresh the current design with a few extra convenience controls and keep the parts simple and larger so it is easier for DIY building.

Feel free to weigh in....

KittenVillage, 2025-03-25:
Personally I'm comfortable building 0603 on up. I'd much prefer to pcba something that has a large pin count cpu. (I've got a couple of boards here with 144 pin chips, and the pads are so narrow! I can do drag soldering, but across 36 pins a side?) QFN packages are the scariest for me. And 0402 because I do a lot of layout with solder paste and hot air reflow and that size can just blow away and disappear.

I saw an 0603 handsoldering pad footprint in kicad or eagle the other day. That seems like a sensible solution for diy modules. Still able to cram an 0805 onto there if you need to sub out a value...

I'd love a PCBA from your next version. I think you should update it to a better microcontroller for more features because honestly your builds look awesome and I wouldn't want to hold you back. I did think the cpu on the Oscar right now look hand solderable. Some of your other modules with larger cpus look kinda daunting. (Though so intriguing in function...) But I think that diy builders out there can figure out your builds alright.

dchwebb, 2025-03-26:
Thanks for the feedback. I don't think I would need to go above a 100 pin microcontroller, and could probably get away with less if the part was available. The main issue is that the more powerful micros are more power hungry so I would have to use a dual power supply.

I am also going to add a USB connection. I would normally use a USB C socket, but they are very fiddly to solder so could probably fit a full sized USB B socket on their which are pretty easy to do. Any thoughts?

modulove, 2025-03-26:
Just wanted to signal interest as well.

We very much liked the easy build of the Punck modules that I had orderd with PCBA service.
I am more of a pick and place guy because of time constraints and lack of smd experience but think within our group we could make both the simple or advaned version. Liked the full sized socket on the Punck because easy mounting as well as availability.

This is awesome, Oscar seem to be indeed a good upgrade from nano powered scope :)
Thanks for your effords!

dchwebb, 2025-03-26:
The features I definitely want to add are:

-	Three illuminated buttons for channel selection
-	A separate button to open the menu, freeing up the encoder buttons to handle changing the mode forwards and backwards.
-	A USB input – to enable more advanced configuration and also MIDI USB analysis tools.
-	I’ll probably also add a mult to the serial MIDI input and use an optocoupler on the input

The primary goal is to make navigation and channel selection faster and simpler. The module is pretty good now, but the main benefits of a faster microcontroller would be to allow analysis of higher speed signals. I could possibly also do something like MIDI pass-through allowing USB MIDI to converted dynamically to serial USB and vice versa - though not really sure that belongs on an oscilloscope ...

dchwebb, 2025-06-24:
Principal changes/improvements are:

- Illuminated push buttons for quick channel selection
- USB C socket for analysis of USB MIDI data and firmware updates
- Optocoupler on serial MIDI input, and addition of passive MIDI mult
- Increasing horizontal zoom to 1 second for use with LFOs, envelopes etc
- Better handling of triggering with slow signals

In addition going forward I will only be updating the firmware for v3. I do have some spare PCBs and built modules so will be offering those out in due course. If you'd like one let me know.

KeenVox, 2025-06-24:
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

Is the display still the same as V2?

modulove, 2025-06-25:
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

Thanks! I have put a few in my basket for the next jlcpcb order.
Will share them with my team in our lab.

modulove, 2025-07-10:
Just wanted to update here as we build two last night and we like them very much.
Now to test everything in depth.

For the USB-C connector i want to ask, if changing to somthing like this would be possible? https://www.mouser.de/ProductDetail/Same-Sky/UJ20-C-V-C-2-SMT-TR?qs=i8QVZAFTkqQoVh6KAV6XdA%3D%3D

Thanks for all your work!
This project is very nicely documented and a joy to build.

Cheers
Linus

dchwebb, 2025-07-10:
Glad you like it!

Sadly that USB connector won't quite work as it is just not high enough to poke through the front plate. It really needs to be around 12mm up from the PCB and that one is 10mm. I guess you could use a tiny interposer board to raise it up a bit but not ideal.

I've looked high and low for a vertical mount USB C socket with pins rather than SMD legs and drawn a blank everywhere. The only other one I have found which is high enough is a full-sized USB B socket, but that is too high for most designs.

KeLaiFu, 2025-07-10:
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

can we expect a video on your IG?

modulove, 2025-07-16:
I will share something soon on IG, I am about to move to a new case and there is space for the Oscar 👌

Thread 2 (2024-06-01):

Screen Blank problem?

lpflpf889, 2024-06-01:
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

After assembling the hardware, I flashed the Oscar446.elf firmware directly, but the screen displays as white with no information. What could possibly be the issue here? Is it likely a problem with the bootloader or some other hardware malfunction?

dchwebb, 2024-06-01:
Hard to tell without seeing it directly, but first guess would be a soldering issue. If you have an oscilloscope or logic analyser you could probe the pins marked MOSI and SCK on the display daughterboard. If the microcontroller is outputting SPI data to the screen you will see activity on those pins. If you don't have an oscilloscope you could use a multimeter to probe the same pins. I would expect a voltage around 1.7V on the SCK pin (as it is a clock signal that is 3.3V for half the time and 0V the other half). MOSI should be slightly less.

Tracing those signals back to the main board and to the microcontroller will possibly give further clues as to where the issue is.

Another troubleshooting path is to check that the microcontroller is working. To do that you would need to download the firmware source code from Github and open the project in STM Cube IDE. With the ST-link connected to the module you can then start debugging the project. If part of the hardware is not working (eg the external oscillator) you will see the application halt in the clock initialisation code.

Sorry if this is a bit vague, but I would need a lot more information to provide decent assistance - higher resolution pictures of front and back would be a good start. Also if you can tell me what test equipment and experience you have I can tailor advice better.

lpflpf889, 2024-06-07:
I tested my 8MHz crystal oscillator with an oscilloscope, but it did not start oscillating. The IDE displayed as follows; measured input voltages of -12V and +11.3V using a multimeter. Attached is a picture of my PCB.
Still not work，please help me~

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
<img width="1260" alt="20240607234412" src=https://github.com/dchwebb/Oscar/assets/91143125/c73569f9-3034-4135-a67f-35fce2b5fa0b">

dchwebb, 2024-06-08:
From the photograph it looks like there might be some solder bridges at the top right of the microcontroller. In this area are the Reset line, the crystal and the LCD DC and LCD Reset lines. If it looks like there might be bridges you can use the continuity mode on the multimeter to test for shorts. If there are solder bridges some flux and desoldering braid should be able to clear up.

Another thing to test is the 3.3v power rail - without that the microcontroller won't function.

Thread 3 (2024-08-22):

Datasheet link broken for LCD Panel

masl123, 2024-08-22:
Hey,
I'm interested in building the module. I will do some of the fixes mentioned in the schematic... Notably the easy ones like adding capacitors to the Opamps and Resistor to Boot0 and also maybe the optos for the midi connection....

Sadly the Datasheet Link ([this one](http://pan.baidu.com/s/11Y990)) for the LCD screen in the schematic is broken and there seems to be no information about the exact dimensions of the Screen available anywhere else.

I tried to identify which screen is needed: There are two sizes of LCDs with the IL9341 available that have an 18-Pin connection and might fit: 2.4 and 2.8 inch (see [2.4 inch aliexpress](https://www.aliexpress.com/item/32808378937.html) or [2.8 inch aliexpress](https://www.aliexpress.com/item/1005007014087481.html)). Which is the correct one? Note: Both offers have the dimensions in the listing.

Another Question: Did you only buy the Panels (like in the above listings) or did you get one of those "cheap" PCBs with a Panel already soldered onto it and removed the Panel somehow?

dchwebb, 2024-08-23:
The correct version is the 2.4 inch with 4 wire SPI connection. Eg:

https://www.ebay.co.uk/itm/394725476377
https://www.ebay.co.uk/itm/155133297926

The one in the first aliexpress link above also looks correct.

I'm not sure I would bother with the opto-coupler for the MIDI in as the MIDI function is just diagnostic, so any noise introduced from the ground line can just be solved by unplugging it.

However you may want to redesign the MIDI connection as I designed it before the MIDI over TRS was standardised. If you use a proper TRS socket (Eg the PJ366ST at https://www.thonk.co.uk/shop/thonkiconn/ ) then I would connect the tip to the MIDI input and the sleeve to ground. The ring should be left floating. That will conform to the new MIDI standard.

Closed 2024-10-10.

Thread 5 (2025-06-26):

requesting a picture of oscar v3

KeLaiFu, 2025-06-26:
I know this is painfully trivial, so forgive me but is there any room on the right side of the LCD daugher board to shuffe the screen the 1mm or so to the left to make it sit central to the module? If the pin headers are in the way we could fix that by using SMD headers, but I couldnt see any pictures of the module and screen assembled to see if any part of the screen would prevent it.

Thanks again for your contributions and tollerance for stupid questions like this...

dchwebb, 2025-06-27:
Not without increasing the size of the module - I have pushed it as far over as I could, but the LCD is not symmetrical.

I can't put the mounting pins above the module, either as that doesn't leave enough clearance for mounting to a Eurorack frame.

It's annoying, I know, but I felt that using extra HP wasn't worth it.

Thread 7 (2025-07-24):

Frozen after ~1h

tsanderakis, 2025-07-24:
Was in the kitchen for some food and after ~1h module was frozen  Full buffer?
Did a reset and after another long? time again frozen. Tomorrow I have a little bit more time and maybe start it together with an alarm clock to messure a little bit the time and maybe I can tell a little bit more.

dchwebb, 2025-07-24:
What mode was it in? If it happens again some sort of picture of what was on the screen would be useful.

tsanderakis, 2025-07-24:
Picture is from frozen module.

tsanderakis, 2025-07-24:
one  more frozen picture
room temperature is 24° celsius

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

tsanderakis, 2025-07-24:
2 more

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

tsanderakis, 2025-07-25:
Its definitely the module here on the table I think. Voltage +-12V and +3.3 is full ok, but the time between working and freezing is now parts of a second. Slow death of what? Whats interesting is, that I can talk to the frozen module with my disco board. Reading firmware is ok and also writing. And I waisted  a lot of flux and IPA last evening. Will later think a little bit about the display. Frozen display or frozen STM + display? A new display will be another 10 days from China.

tsanderakis, 2025-07-25:
Machine from hell back to live.
Think I found it. Was a problem with the solder connection of the display to the riser board. Removed the display with a small screwdriver, because it was fixed with a little bit of removable glue, a little bit of flux and the magic was done.
Will test now a little bit more....

tsanderakis, 2025-07-25:
Only the PCBs are from JLCPCB. Everything else old school handsoldered with my 40 years old Weller.
Mostly quality parts from Mouser or Digikey. The regulator not and of course the display. I bought a few years ago a lot of AMS 3.3V from Aliexpress and I`m still ok with them. Used them a lot in Mutable Instruments modules. All together I`m somewhere around 250 modules in my small apartment and around 50 of them still in a box and not used. But want to build in the next few month something with 168x15 just for drums. But think that then I come to my limit or find a bigger place wher to stay.
So coming back to the regulator: in my opinion not to hot or working at its limit. Yesterday evening we had here 24° Celsius, but other parts of Europe especially in the south have sometimes 40°. Maybe these people will have problems? My cases have a small slit on top and bottom for ventilation like a chimney. Never had problems.
Coming back to STMs. I also bought some from Aliexpress and never had problems with a company called SUHMS.
Seen in your Github something with Casio CZ and they use the same STMs like the bigger Mutable modules like Clouds, Elements. This is maybe something for the next month and I have  ~5 STMs laying around. Are the gerbers ok for this Casio CZ Module or is there a lot to do with missing tracks?
Oscar still running. Going now for 1h to our garden giving tomatoes and cucumbers a little bit of water, feeding our five fishies from my nice and when Oscar is still working and was not burning down our house, everything is ok.
Later I will have a look to the MidiMonger which I did in the beginning of this week. Want to connect my old Roli Seaboard to my modular department. Midi MPE is normaly poly, but you can switch Seaboard into a mono controller and hope that these 4 CV outputs are enough. Waiting for the postman and an adapter for the 12V power supply. Think my Test PSU is not strong enough to power the Seaboard. In my other cases I use 65er MeanWells and there is around 5A on the 5V line. Seaboard is dragging around 1,3A and this would be fine in the big cases, but I think that this additional 12V thing will help. Seaboard has only USB and Bluetooth so the Midi Host function caught my attention.

dchwebb, 2025-07-25:
Oscar is quite power hungry, mainly because it is constantly driving screen updates over SPI which uses a fair amount of power. I've just made a couple of tweaks to the PCBs to increase the heat sink via sizes to try and better distribute the heat away from the regulator, but that won't help you now :(

Also one thing worth mentioning about MidiMonger - it is not suitable to provide 5v to very power hungry devices. I'm not sure how the Seaboard is powered (or what its current draw is) but the 5V regulator in MidiMonger is probably only capable of outputting USB 5V at 100-150mA without getting very hot.

tsanderakis, 2025-07-25:
Back home. No fire brigade, no smoke and Oscar still working.
Heat sink? Just thinking about my Raspberry Computers and there was also the problem with heat. They are selling for small money mini heatsinks for Rasberry. Why not putting one on top of the regulator or a bigger one onto the other side of the PCB?
Habe two laying around and try later if they fit.
https://www.ebay.de/itm/405888369922?itemid=405888369922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

With MidiMonger we will see later if this small adapter arrives in time. Think when the Seaboard is then powered from the 12V external PSU there will be no problem.

Closed 2025-07-25.

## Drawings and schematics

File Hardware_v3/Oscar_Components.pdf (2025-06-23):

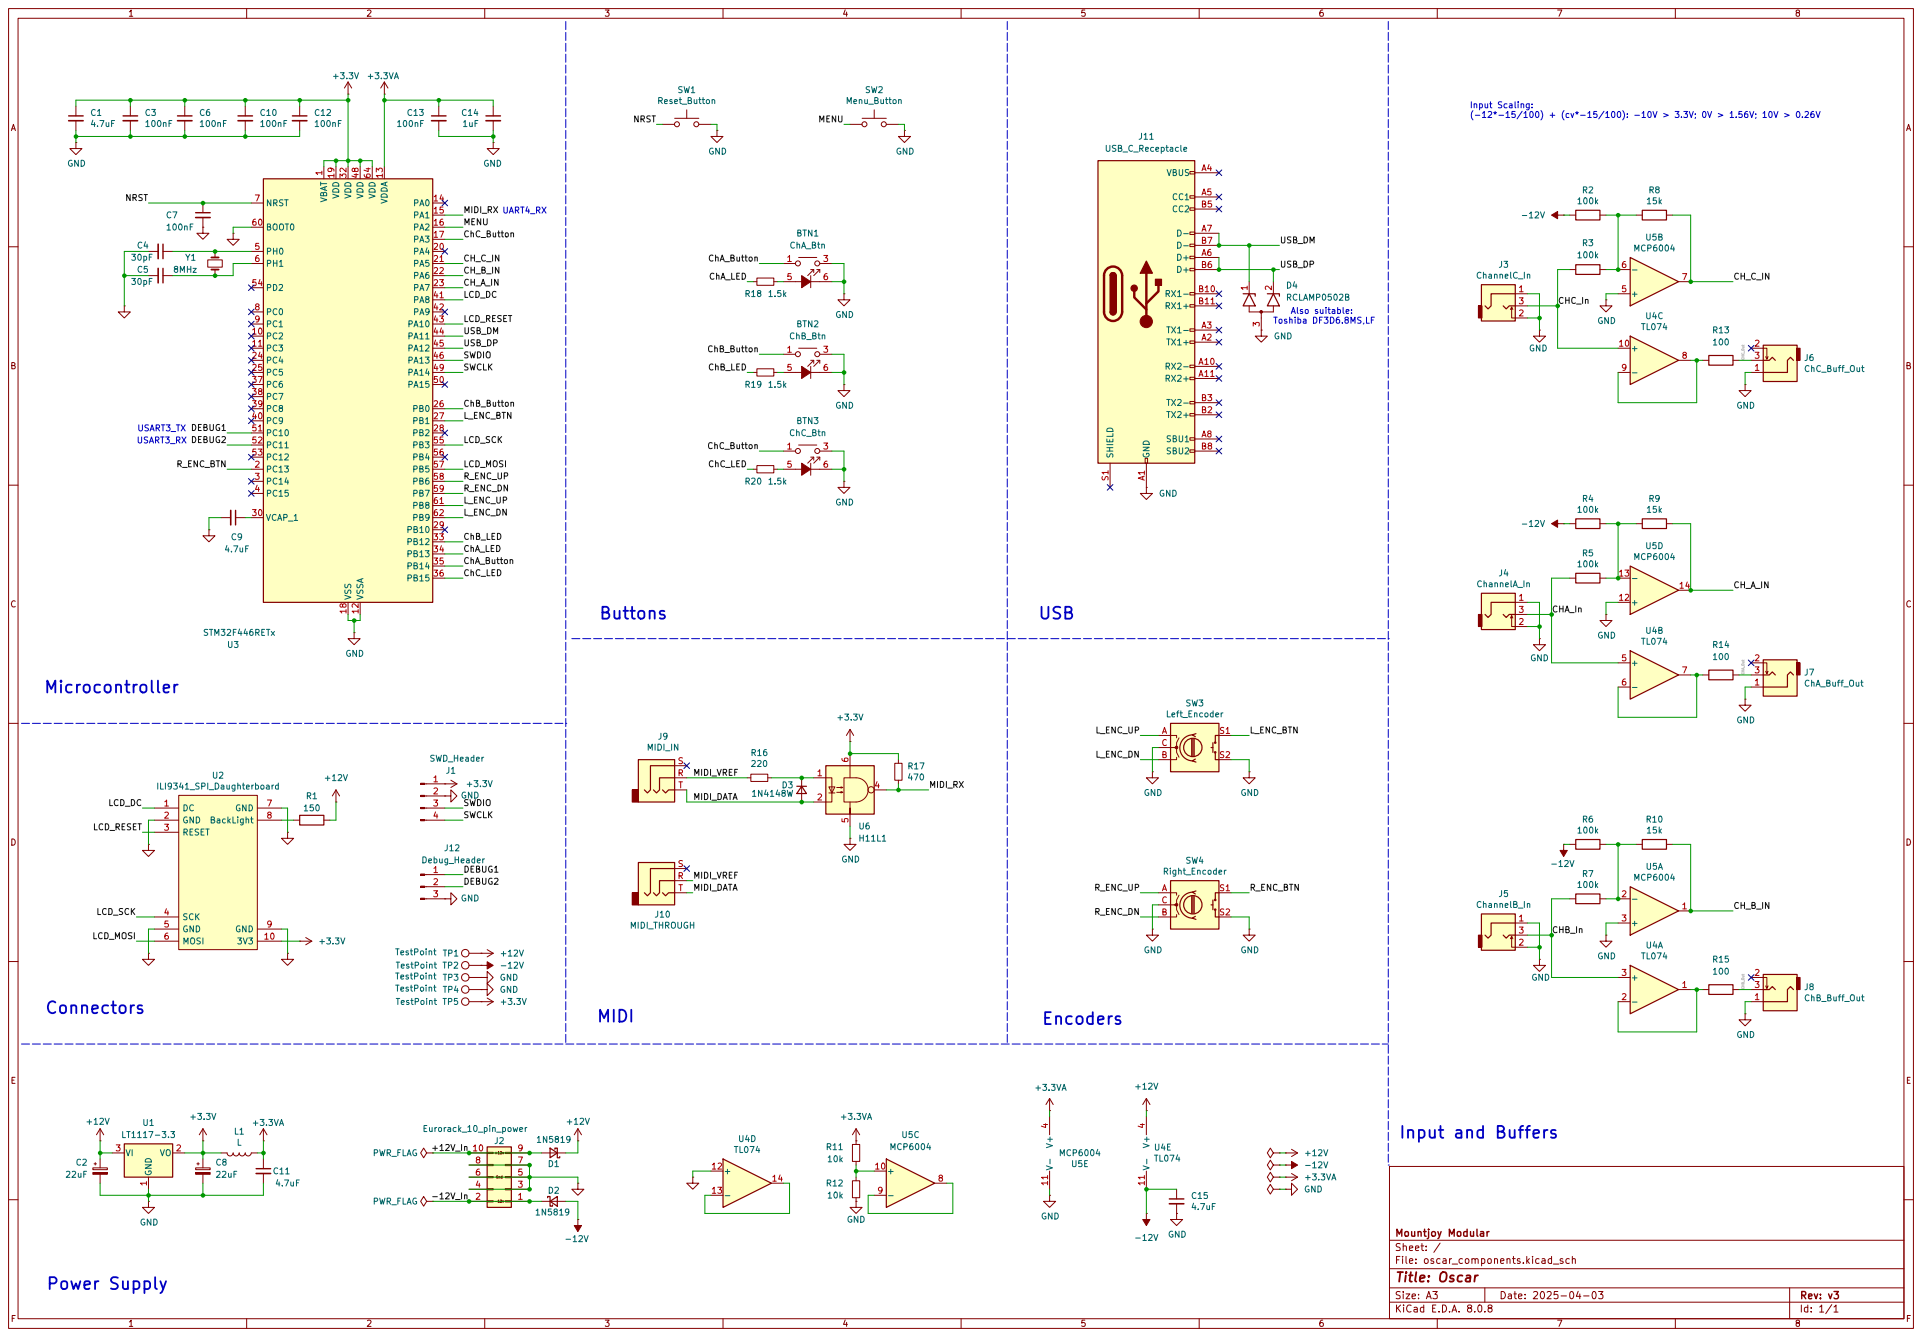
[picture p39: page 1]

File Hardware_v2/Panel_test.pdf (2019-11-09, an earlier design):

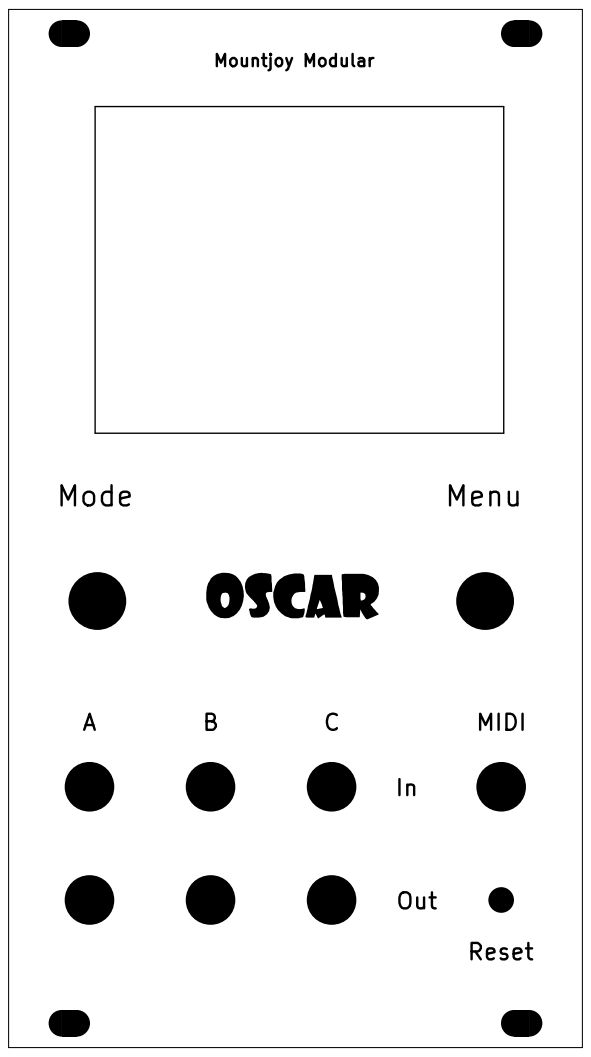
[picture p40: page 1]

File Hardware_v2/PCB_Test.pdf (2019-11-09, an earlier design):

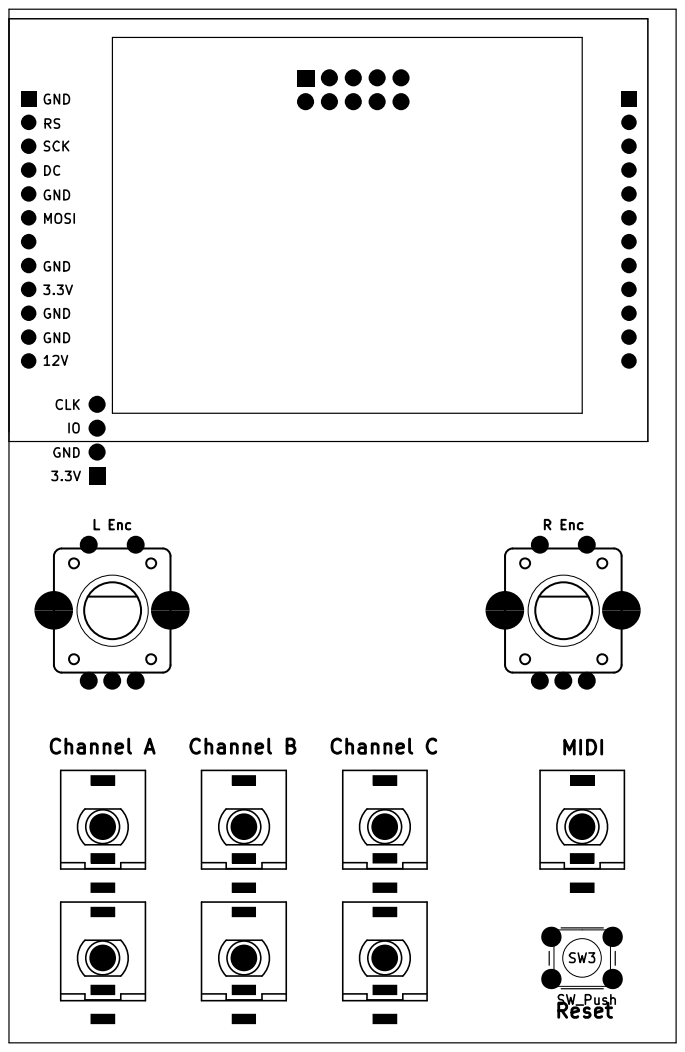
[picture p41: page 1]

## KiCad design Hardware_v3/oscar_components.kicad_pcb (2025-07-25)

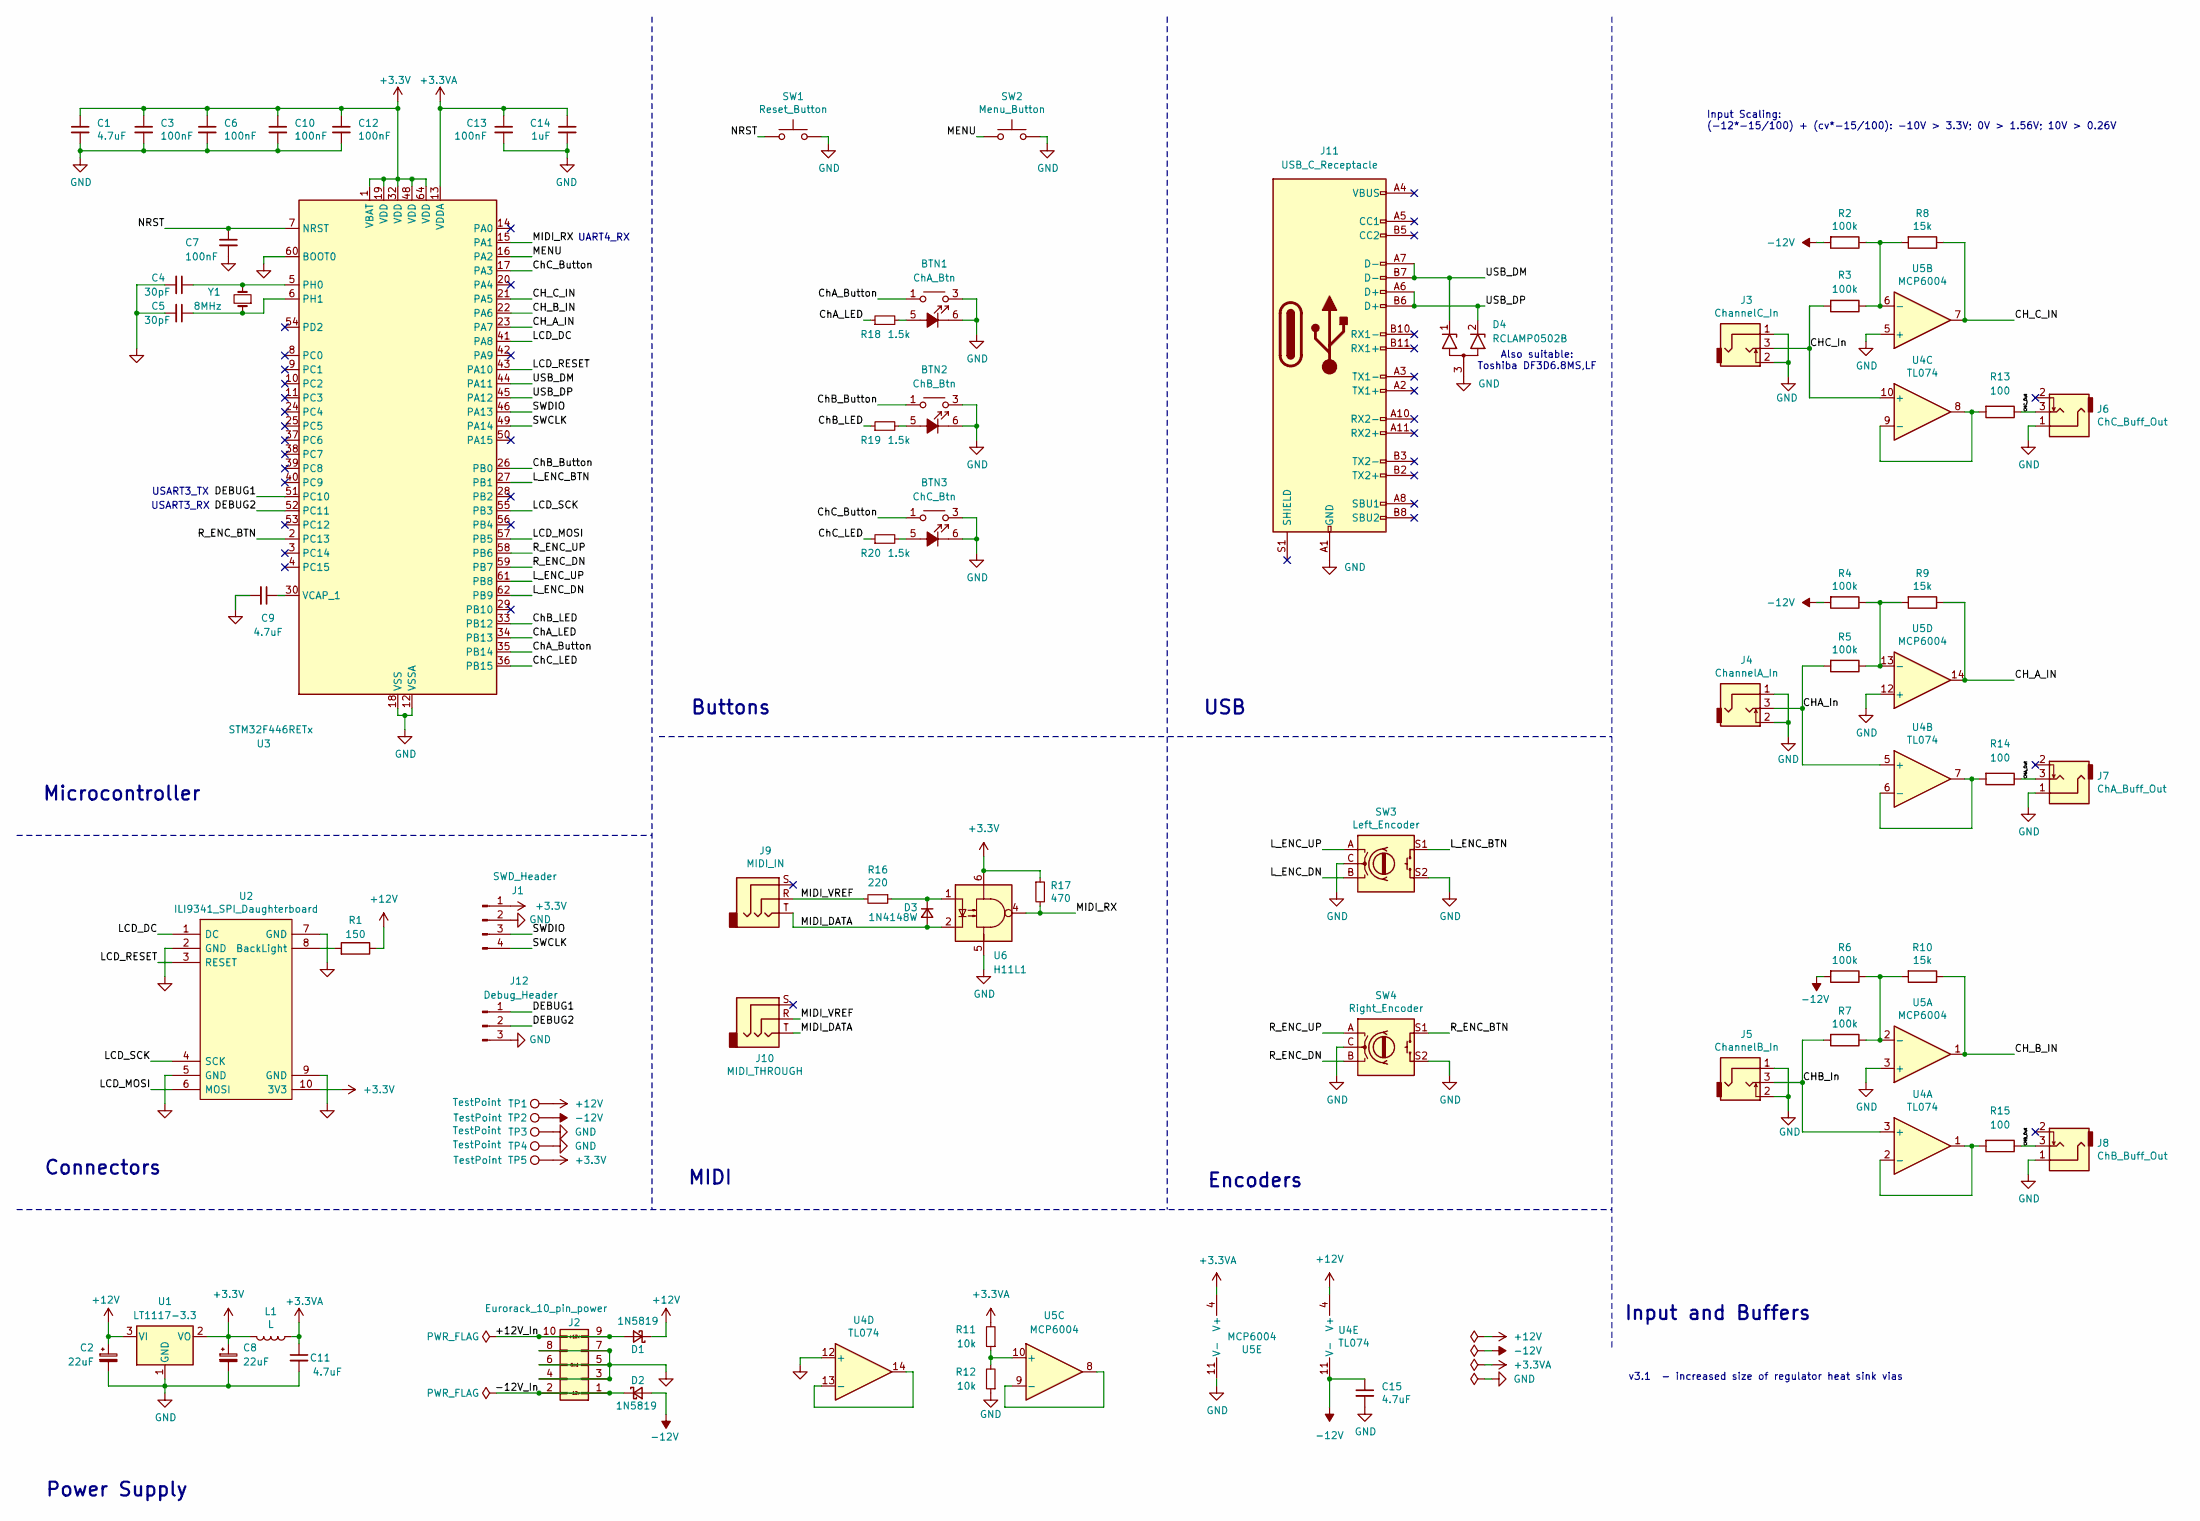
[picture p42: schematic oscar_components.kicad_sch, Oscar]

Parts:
BTN1: ChA_Btn; Low_Profile_LED_Button
BTN2: ChB_Btn; Low_Profile_LED_Button
BTN3: ChC_Btn; Low_Profile_LED_Button
C1, C9, C11, C15: 4.7uF; C_0805_2012Metric
C2, C8: 22uF; CP_Elec_4x5.8
C3, C6, C7, C10, C12, C13: 100nF; C_0805_2012Metric
C4, C5: 30pF; C_0603_1608Metric_Pad1.08x0.95mm_HandSolder
C14: 1uF; C_0805_2012Metric
D1, D2: 1N5819; D_SOD-123
D3: 1N4148W; D_SOD-123
D4: RCLAMP0502B; SOT-416
J1: SWD_Header; SWD_header
J2: Eurorack_10_pin_power; Eurorack_10_pin_header
J3: ChannelC_In; THONKICONN_hole
J4: ChannelA_In; THONKICONN_hole
J5: ChannelB_In; THONKICONN_hole
J6: ChC_Buff_Out; THONKICONN_hole
J7: ChA_Buff_Out; THONKICONN_hole
J8: ChB_Buff_Out; THONKICONN_hole
J9: MIDI_IN; Thonkiconn_Stereo-PJ366ST
J10: MIDI_THROUGH; Thonkiconn_Stereo-PJ366ST
J11: USB_C_Receptacle; USB_C_Receptacle_Amphenol_12401951E412A
J12: Debug_Header; PinHeader_1x03_P2.54mm_Vertical
L1: L; R_0805_2012Metric
R1: 150; R_0805_2012Metric
R2, R3, R4, R5, R6, R7: 100k; R_0805_2012Metric
R8, R9, R10: 15k; R_0805_2012Metric
R11, R12: 10k; R_0805_2012Metric; Part_Number C23162
R13, R14, R15: 100; R_0805_2012Metric
R16: 220; R_0805_2012Metric
R17: 470; R_0805_2012Metric
R18, R19, R20: 1.5k; R_0805_2012Metric; Part_Number C23162
SW1: Reset_Button; SW_PUSH_6mm_aligned
SW2: Menu_Button; SW_PUSH_6mm_aligned
SW3: Left_Encoder; Encoder
SW4: Right_Encoder; Encoder
TP1, TP2, TP3, TP4, TP5: TestPoint; 1.3mm_Test_Point
U1: LT1117-3.3; SOT-223-3_TabPin2
U2: ILI9341_SPI_Daughterboard; ILI9341_SPI_daughterboard_v2
U3: STM32F446RETx; LQFP-64_10x10mm_P0.5mm
U4: TL074; SOIC-14_3.9x8.7mm_P1.27mm
U5: MCP6004; SOIC-14_3.9x8.7mm_P1.27mm
U6: H11L1
Y1: 8MHz; Crystal_SMD_5032-2Pin_5.0x3.2mm_Large_Pads

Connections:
+3.3V: C1.1, C3.1, C6.1, C8.1, C10.1, C12.1, J1.1, L1.2, R17.1, TP5.1, U1.2 (VO), U2.10 (3V3), U3.1 (VBAT), U3.19 (VDD), U3.32 (VDD), U3.48 (VDD), U3.64 (VDD), U6.6
+3.3VA: C11.1, C13.1, C14.1, L1.1, R11.2, U3.13 (VDDA), U5.4 (V+)
+12V: C2.1, D1.1 (K), R1.1, TP1.1, U1.3 (VI), U4.4 (V+)
-12V: C15.1, D2.2 (A), R2.2, R4.2, R6.2, TP2.1, U4.11 (V-)
/+12V_In: D1.2 (A), J2.9, J2.10
/-12V_In: D2.1 (K), J2.1, J2.2
/CHA_In: J4.3, R5.2, U4.5 (+)
/CHA_Out: J7.3, R14.1
/CHB_In: J5.3, R7.2, U4.3 (+)
/CHB_Out: J8.3, R15.1
/CHC_In: J3.3, R3.2, U4.10 (+)
/CHC_Out: J6.3, R13.1
/CH_A_IN: R9.1, U3.23 (PA7), U5.14
/CH_B_IN: R10.1, U3.22 (PA6), U5.1
/CH_C_IN: R8.1, U3.21 (PA5), U5.7
/ChA_Button: BTN1.1, BTN1.2, U3.35 (PB14)
/ChA_LED: R18.1, U3.34 (PB13)
/ChB_Button: BTN2.1, BTN2.2, U3.26 (PB0)
/ChB_LED: R19.1, U3.33 (PB12)
/ChC_Button: BTN3.1, BTN3.2, U3.17 (PA3)
/ChC_LED: R20.1, U3.36 (PB15)
/DEBUG1: J12.1, U3.51 (PC10)
/DEBUG2: J12.2, U3.52 (PC11)
/LCD_DC: U2.1 (DC), U3.41 (PA8)
/LCD_MOSI: U2.6 (MOSI), U3.57 (PB5)
/LCD_RESET: U2.3 (RESET), U3.43 (PA10)
/LCD_SCK: U2.4 (SCK), U3.55 (PB3)
/L_ENC_BTN: SW3.S1, U3.27 (PB1)
/L_ENC_DN: SW3.B, U3.62 (PB9)
/L_ENC_UP: SW3.A, U3.61 (PB8)
/MENU: SW2.1, U3.16 (PA2)
/MIDI_DATA: D3.2 (A), J9.T, J10.T, U6.2
/MIDI_RX: R17.2, U3.15 (PA1), U6.4
/MIDI_VREF: J9.R, J10.R, R16.2
/NRST: C7.1, SW1.1, U3.7 (NRST)
/R_ENC_BTN: SW4.S1, U3.2 (PC13)
/R_ENC_DN: SW4.B, U3.59 (PB7)
/R_ENC_UP: SW4.A, U3.58 (PB6)
/SWCLK: J1.4, U3.49 (PA14)
/SWDIO: J1.3, U3.46 (PA13)
/USB_DM: D4.1 (K1), J11.A7 (D-), J11.B7 (D-), U3.44 (PA11)
/USB_DP: D4.2 (K2), J11.A6 (D+), J11.B6 (D+), U3.45 (PA12)
GND: BTN1.3, BTN1.4, BTN1.6 (K), BTN2.3, BTN2.4, BTN2.6 (K), BTN3.3, BTN3.4, BTN3.6 (K), C1.2, C2.2, C3.2, C4.2, C5.2, C6.2, C7.2, C8.2, C9.2, C10.2, C11.2, C12.2, C13.2, C14.2, C15.2, D4.3 (A), J1.2, J2.3, J2.4, J2.5, J2.6, J2.7, J2.8, J3.1, J3.2, J4.1, J4.2, J5.1, J5.2, J6.1, J7.1, J8.1, J11.A1 (GND), J11.A12 (GND), J11.B1 (GND), J11.B12 (GND), J12.3, R12.1, SW1.2, SW2.2, SW3.C, SW3.S2, SW4.C, SW4.S2, TP3.1, TP4.1, U1.1 (GND), U2.2 (GND), U2.5 (GND), U2.7 (GND), U2.9 (GND), U3.12 (VSSA), U3.18 (VSS), U3.31 (VSS), U3.47 (VSS), U3.60 (BOOT0), U3.63 (VSS), U4.12 (+), U5.3 (+), U5.5 (+), U5.11 (V-), U5.12 (+), U6.5
unnamed: BTN1.5 (A), R18.2
unnamed: BTN2.5 (A), R19.2
unnamed: BTN3.5 (A), R20.2
unnamed: D3.1 (K), R16.1, U6.1
unnamed: R1.2, U2.8 (BackLight)
unnamed: C4.1, U3.5 (PH0), Y1.2
unnamed: C5.1, U3.6 (PH1), Y1.1
unnamed: C9.1, U3.30 (VCAP_1)
unnamed: R15.2, U4.1, U4.2 (-)
unnamed: R14.2, U4.6 (-), U4.7
unnamed: R13.2, U4.8, U4.9 (-)
unnamed: U4.13 (-), U4.14
unnamed: R6.1, R7.1, R10.2, U5.2 (-)
unnamed: R2.1, R3.1, R8.2, U5.6 (-)
unnamed: R11.1, R12.2, U5.10 (+)
unnamed: U5.8, U5.9 (-)
unnamed: R4.1, R5.1, R9.2, U5.13 (-)

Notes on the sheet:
MIDI
Buttons
USART3_TX
Also suitable: Toshiba DF3D6.8MS,LF
v3.1 - increased size of regulator heat sink vias
Encoders
Microcontroller
Input Scaling: (-12*-15/100) + (cv*-15/100): -10V > 3.3V; 0V > 1.56V; 10V > 0.26V
USART3_RX
UART4_RX
Input and Buffers
Connectors
Power Supply
USB

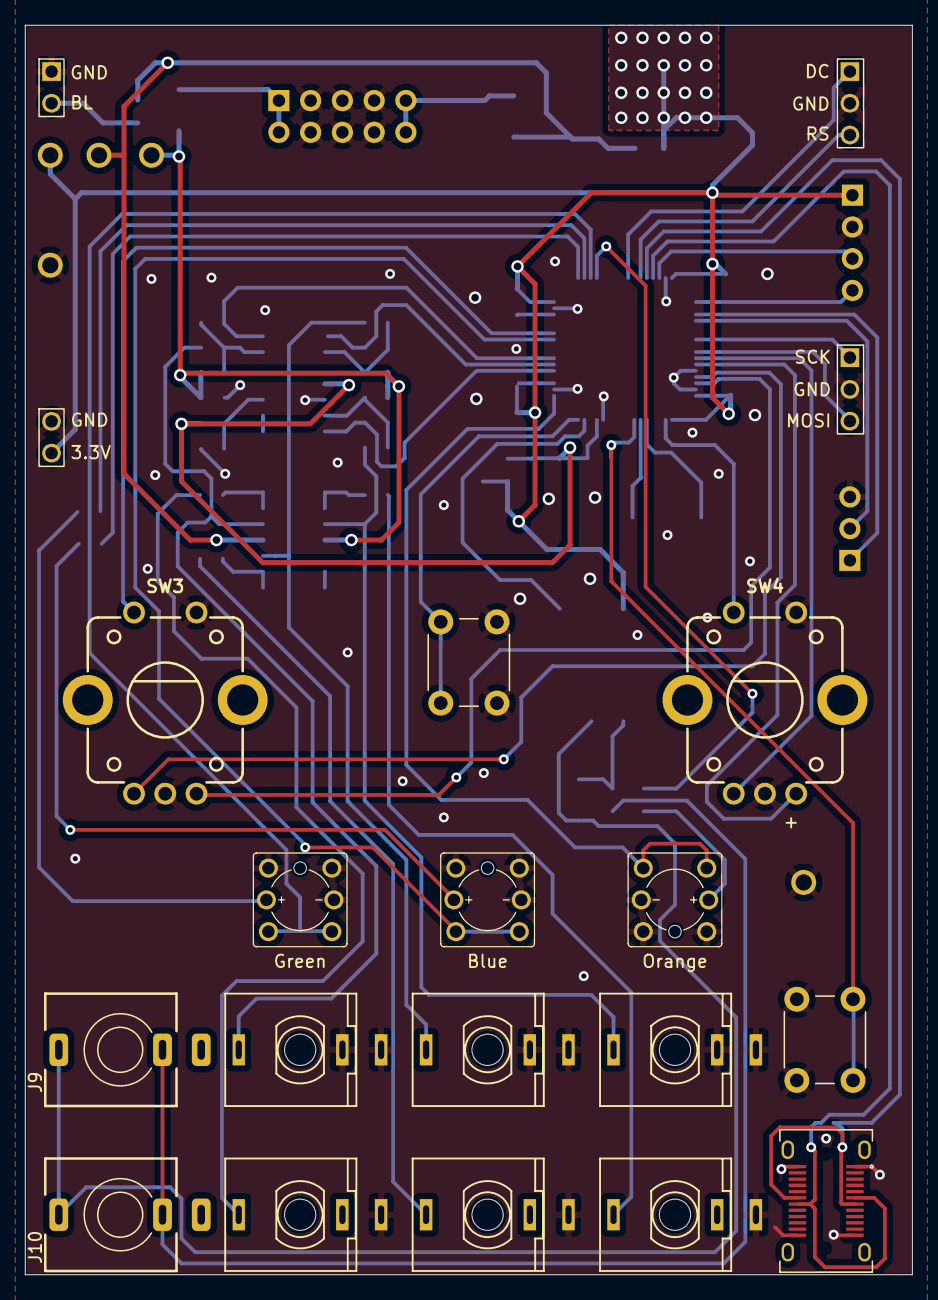
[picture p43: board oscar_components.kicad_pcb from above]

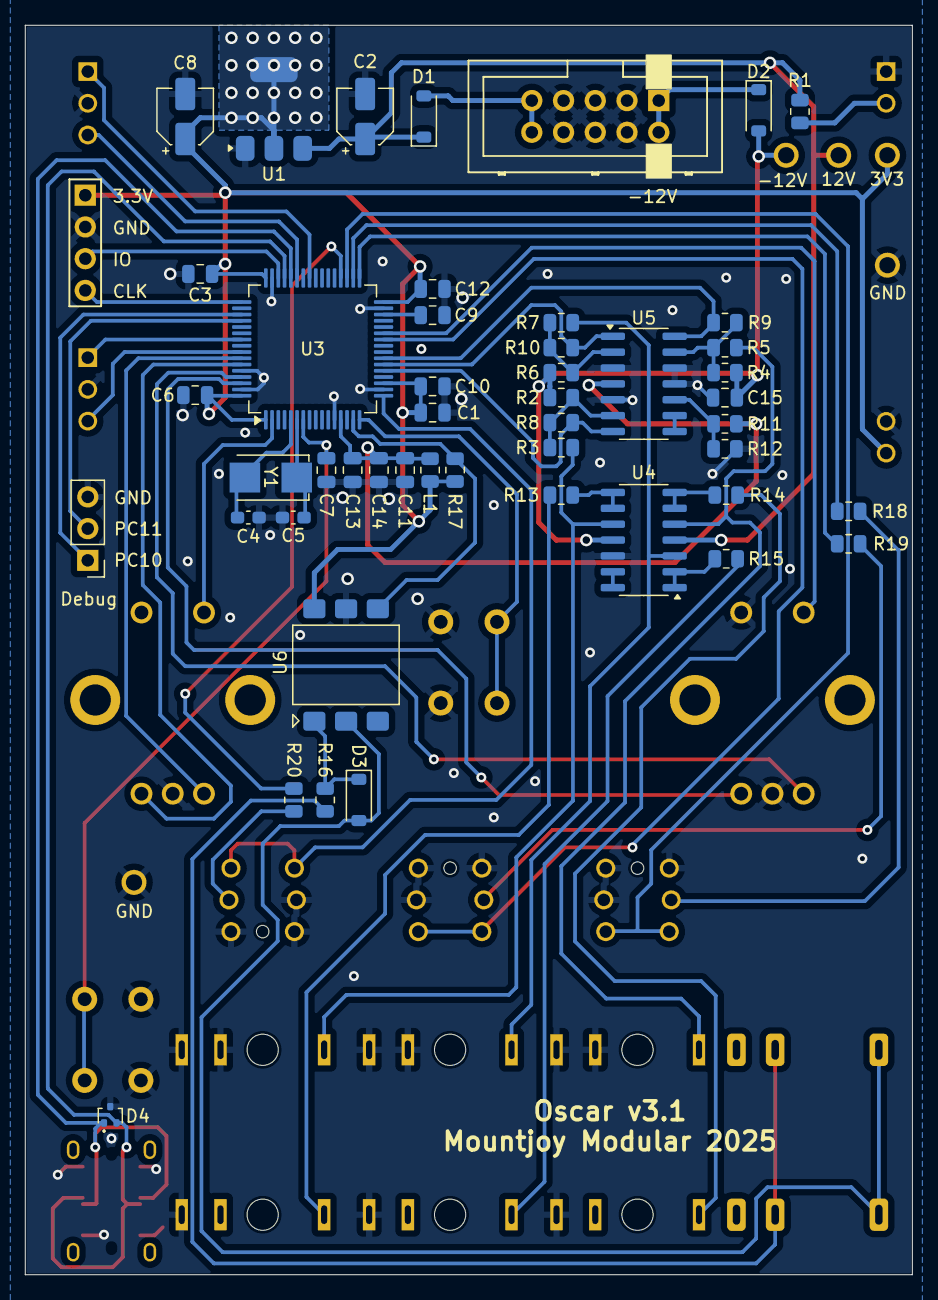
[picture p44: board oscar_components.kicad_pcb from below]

Board: 4 copper layers, 71.0 x 100.0 mm, 71 parts (49 on the bottom side), 60 nets.

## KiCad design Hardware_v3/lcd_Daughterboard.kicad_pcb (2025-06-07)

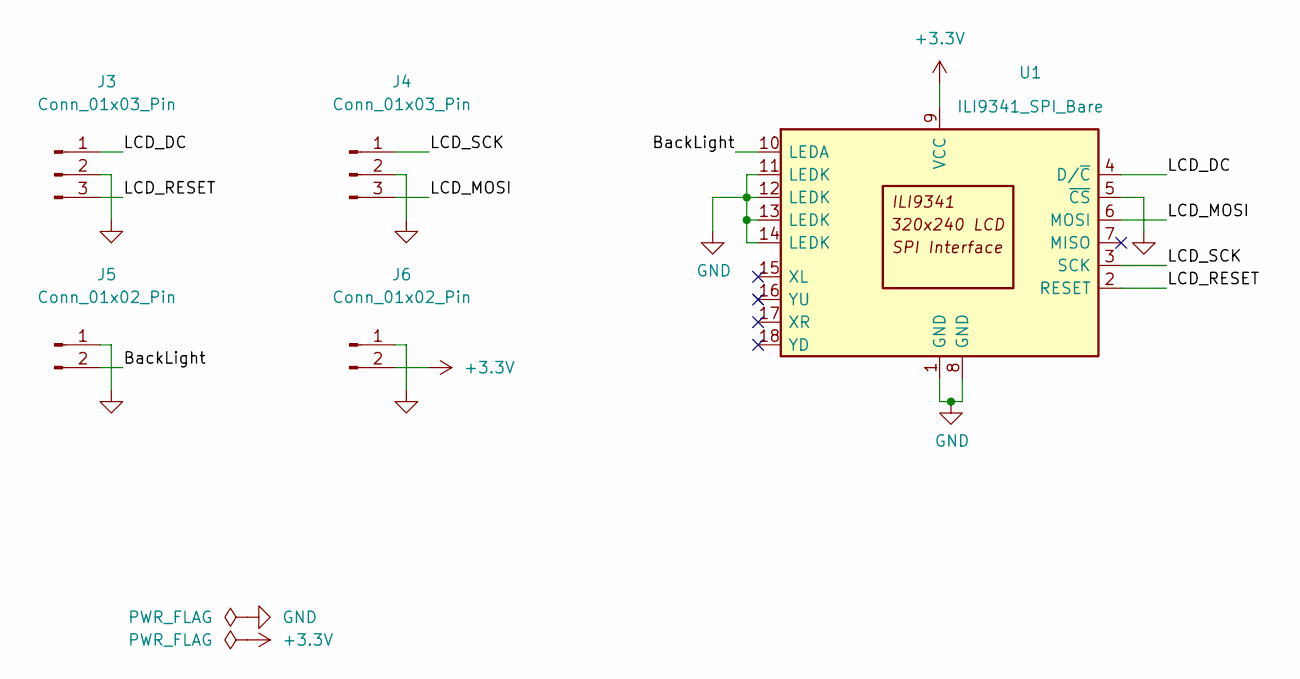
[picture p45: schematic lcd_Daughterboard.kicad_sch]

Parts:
J3, J4: Conn_01x03_Pin; PinHeader_1x03_P2.54mm_Vertical
J5, J6: Conn_01x02_Pin; PinHeader_1x02_P2.54mm_Vertical
U1: ILI9341_SPI_Bare; 18x0.8mmLCDConnector

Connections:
+3.3V: J6.2, U1.9 (VCC)
/BackLight: J5.2, U1.10 (LEDA)
/LCD_DC: J3.1, U1.4 (D/~C)
/LCD_MOSI: J4.3, U1.6 (MOSI)
/LCD_RESET: J3.3, U1.2 (RESET)
/LCD_SCK: J4.1, U1.3 (SCK)
GND: J3.2, J4.2, J5.1, J6.1, U1.1 (GND), U1.5 (~CS), U1.8 (GND), U1.11 (LEDK), U1.12 (LEDK), U1.13 (LEDK), U1.14 (LEDK)

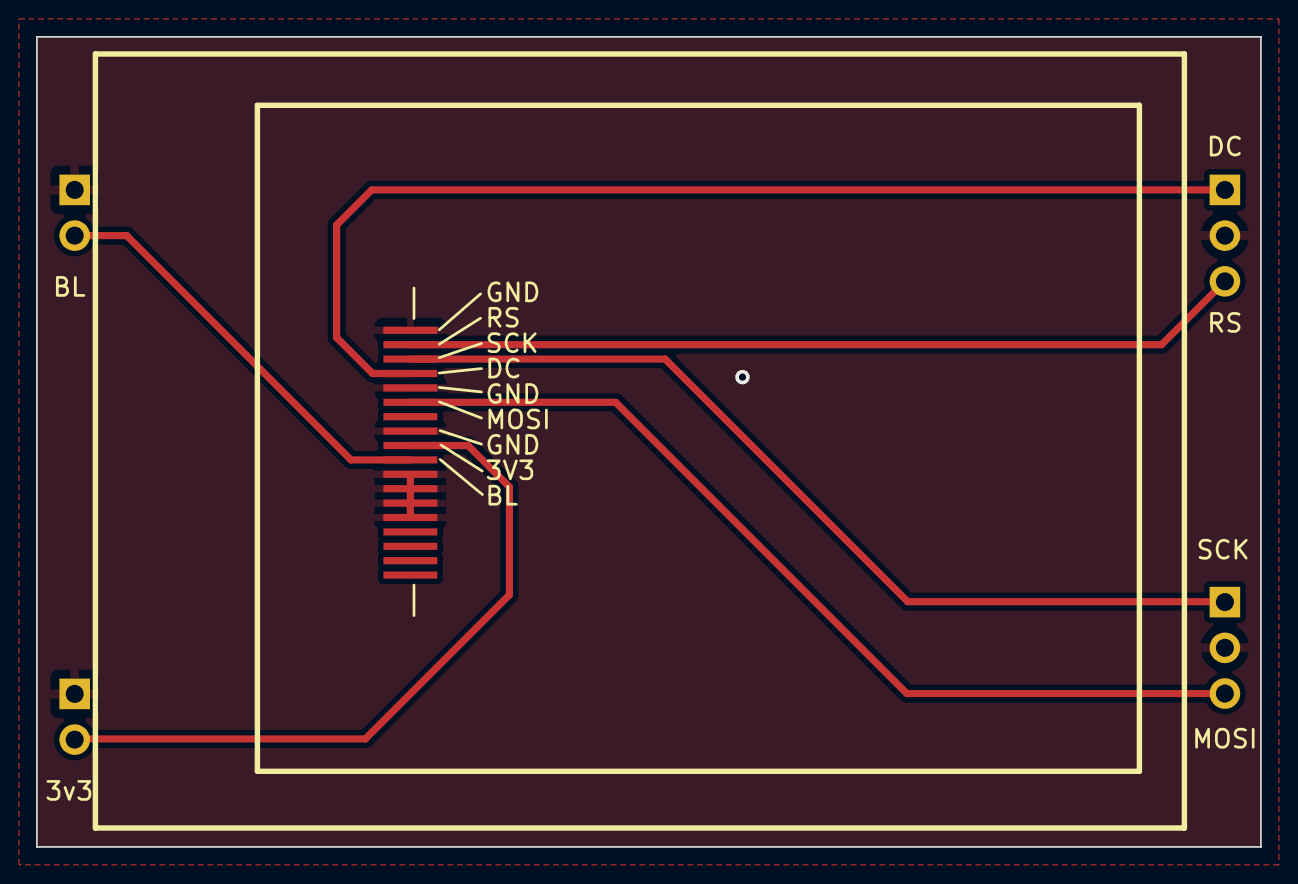
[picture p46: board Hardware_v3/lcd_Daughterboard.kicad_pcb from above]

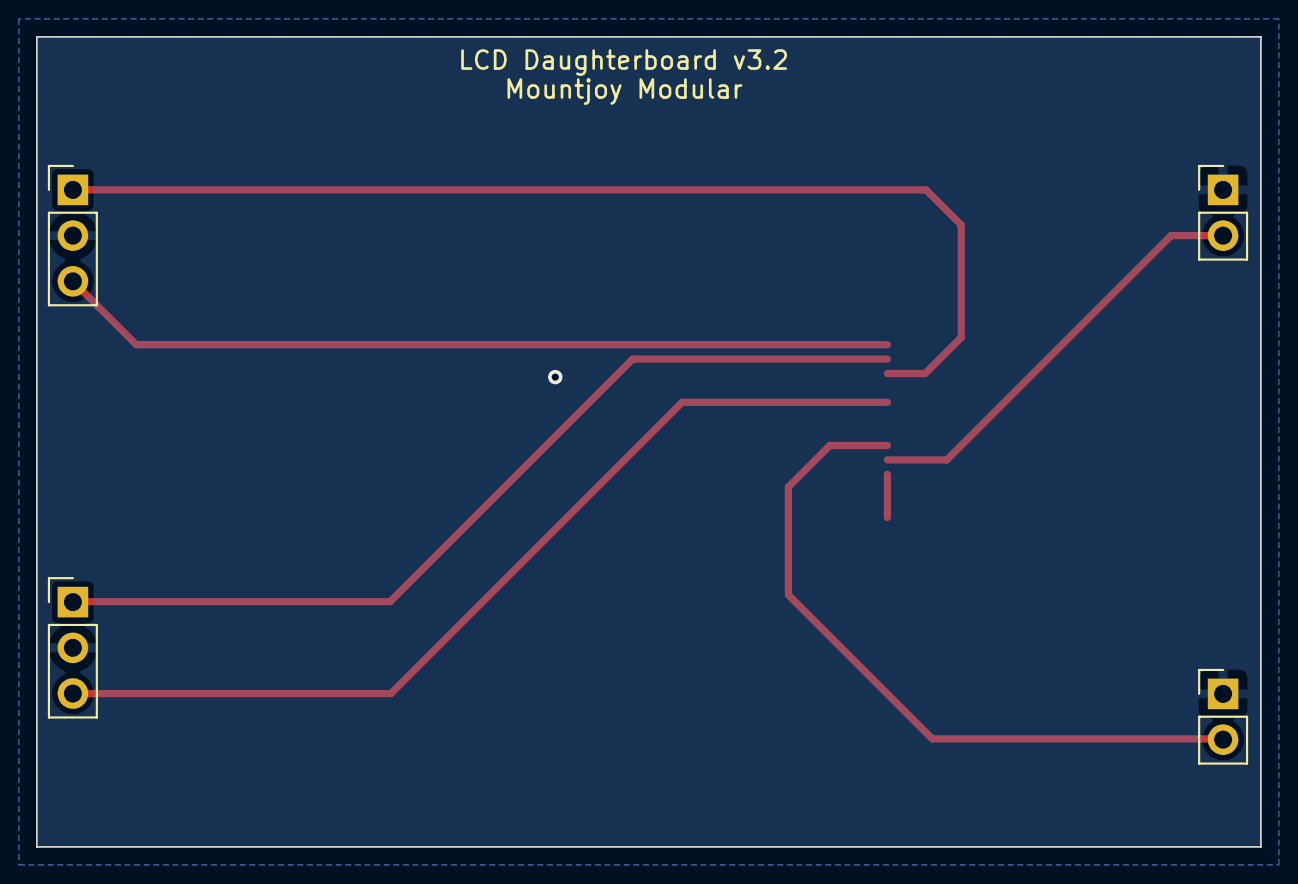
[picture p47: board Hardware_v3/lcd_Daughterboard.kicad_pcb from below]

Board: 2 copper layers, 68.0 x 45.0 mm, 5 parts (4 on the bottom side), 7 nets.

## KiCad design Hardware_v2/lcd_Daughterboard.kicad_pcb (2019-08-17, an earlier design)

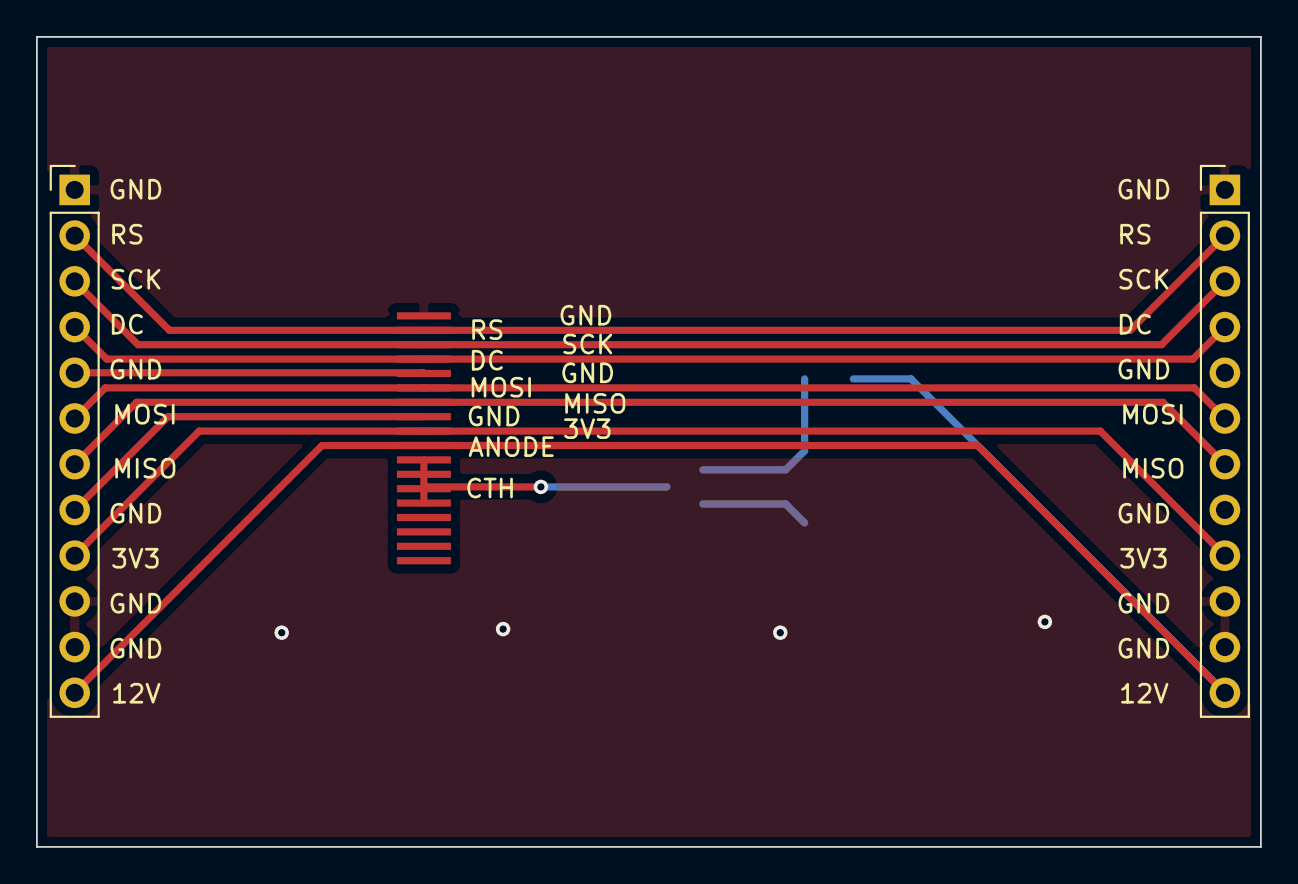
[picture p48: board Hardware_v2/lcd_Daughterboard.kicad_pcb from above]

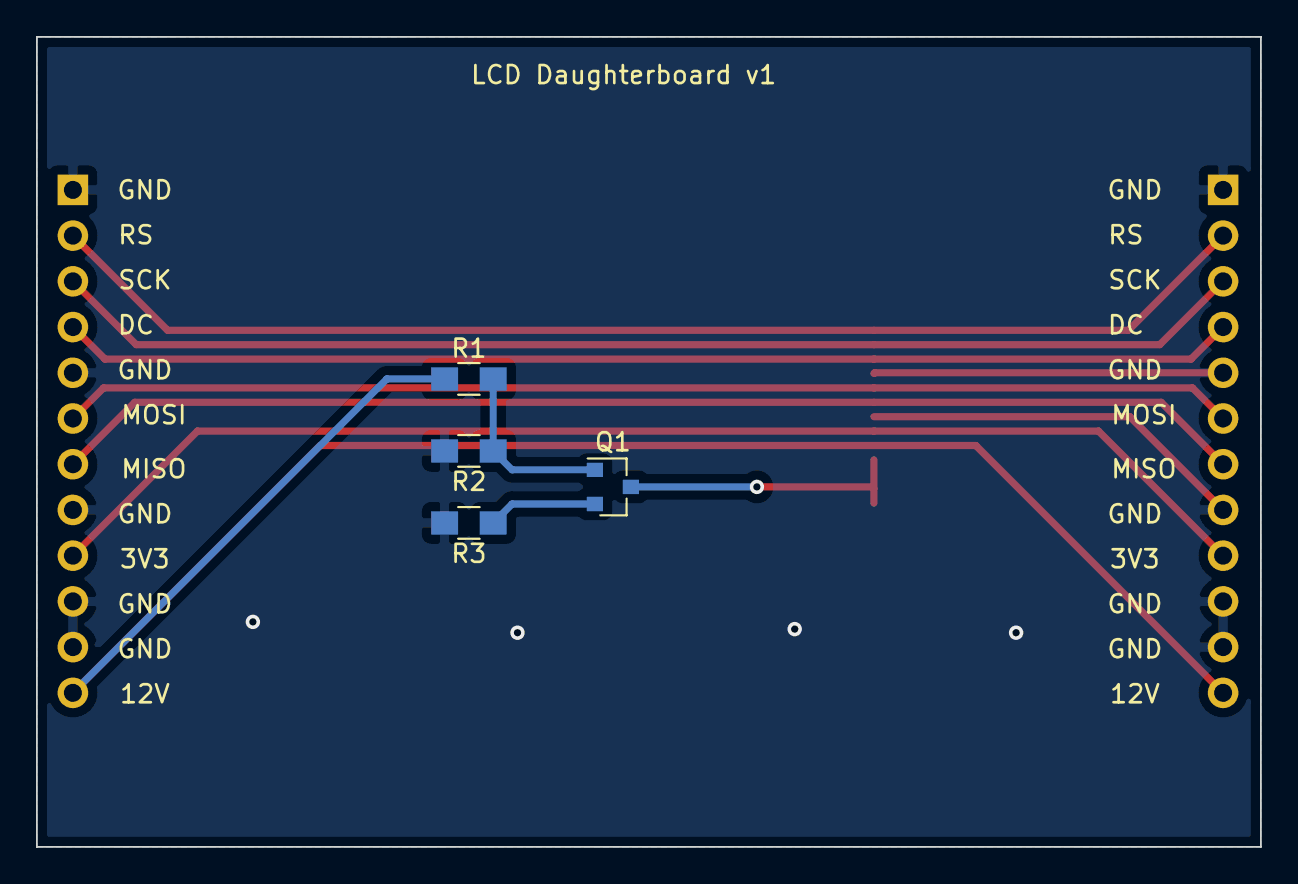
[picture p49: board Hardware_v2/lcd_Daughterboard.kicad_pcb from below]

Board: 2 copper layers, 68.0 x 45.0 mm, 7 parts (4 on the bottom side), 11 nets.

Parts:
J1, J2: Conn_01x12; Pin_Header_Straight_1x12_Pitch2.54mm
Q1: MMBT3904; SOT-23
R1: 220; R_0805_HandSoldering
R2: 1k; R_0805_HandSoldering
R3: 100; R_0805_HandSoldering
U1: ILI9341_SPI_Bare; 18x0.8mmLCDConnector

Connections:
+3V3: J1.9, J2.9, U1.9
GND: J1.1, J1.5, J1.8, J1.10, J1.11, J2.1, J2.5, J2.8, J2.10, J2.11, R2.2, R3.2, U1.1, U1.5, U1.8
LCD_CATHODE: Q1.3, U1.11, U1.12, U1.13, U1.14
LCD_DC: J1.4, J2.4, U1.4
LCD_MISO: J1.7, J2.7, U1.7
LCD_MOSI: J1.6, J2.6, U1.6
LCD_RESET: J1.2, J2.2, U1.2
LCD_SCK: J1.3, J2.3, U1.3
unnamed: Q1.1, R1.2, R2.1
unnamed: Q1.2, R3.1
VCC: J1.12, J2.12, R1.1, U1.10

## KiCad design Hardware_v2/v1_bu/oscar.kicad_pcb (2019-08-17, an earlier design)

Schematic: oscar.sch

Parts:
C1, C4, C6, C7, C8, C9, C10, C16: 100nF; C_0805_HandSoldering
C2, C3: 18pF; C_0805_HandSoldering
C5: 2.2uF; C_0805_HandSoldering
C11, C14: 47uF; CP_Elec_5x5.8
C12, C13: 22uF; CP_Elec_4x5.8
C15: 1uF; CP_Elec_4x5.8
D1, D2: 1N5819; D_SOD-123
J1: SWD_Header; SWD_header
J2: ChannelA_In; THONKICONN_hole
J3: ChannelB_In; THONKICONN_hole
J4: ChannelC_In; THONKICONN_hole
J5: ChA_Buff_Out; THONKICONN_hole
J6: ChB_Buff_Out; THONKICONN_hole
J7: ChC_Buff_Out; THONKICONN_hole
J8: MIDI_In; THONKICONN_hole
J9: Eurorack_16_pin_power; Eurorack_16_pin_header
J10: LCD_Connector; 18x0.8mmLCDConnector
J11: MISO_Connector; SolderWirePad_single_2mmDrill
L1: L; R_0805_HandSoldering
R1, R2, R3, R4, R5, R6: 100k; R_0805_HandSoldering
R7, R8, R9: 15k; R_0805_HandSoldering
R10, R11, R12: 100; R_0805_HandSoldering
SW1: Left_Encoder; Encoder
SW2: Right_Encoder; Encoder
SW3: SW_Push; SW_PUSH_6mm
U1: STM32F446RETx; LQFP-64_10x10mm_P0.5mm
U2: ILI9341_SPI
U3: MCP6004; SOIC-14_N
U4: TL074; SOIC-14_N
U5: LM1117-3.3; TO-252-3_TabPin2
Y1: Crystal; Crystal_SMD

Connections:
+3.3VA: C15.1, C16.1, L1.1, U1.13 (VDDA), U3.4 (V+)
+3V3: C1.1, C4.1, C6.1, C7.1, C14.1, J1.1, J10.9, J10.10, L1.2, U1.19 (VDD), U1.32 (VDD), U1.48 (VDD), U1.64 (VDD), U2.1, U2.8, U5.2 (VO)
+12V: D1.2 (A), J9.9, J9.10
-12V: D2.1 (K), J9.1, J9.2
/CHA_In: J2.3, R2.2, U4.10 (+)
/CHA_Out: J5.3, R10.1
/CHB_In: J3.3, R4.2, U4.5 (+)
/CHB_Out: J6.3, R11.1
/CHC_In: J4.3, R6.2, U4.3 (+)
/CHC_Out: J7.3, R12.1
/MIDI_In: J8.3, U3.10 (+)
CH_A_IN: R7.1, U1.11 (PC3), U3.7
CH_B_IN: R8.1, U1.21 (PA5), U3.14
CH_C_IN: R9.1, U1.14 (PA0), U3.1
GND: C1.2, C2.2, C3.2, C4.2, C5.2, C6.2, C7.2, C8.1, C9.2, C10.2, C11.2, C12.2, C13.1, C14.2, C15.2, C16.2, J1.2, J2.1, J2.2, J3.1, J3.2, J4.1, J4.2, J5.1, J6.1, J7.1, J8.2, J9.3, J9.4, J9.5, J9.6, J9.7, J9.8, J10.1, J10.5, J10.8, J10.11, J10.12, J10.13, J10.14, J10.15, J10.16, J10.17, J10.18, SW1.C, SW1.S2, SW2.C, SW2.S2, SW3.2, U1.12 (VSSA), U1.18 (VSS), U1.31 (VSS), U1.47 (VSS), U1.63 (VSS), U2.2, U2.3, U2.9, U3.3 (+), U3.5 (+), U3.11 (V-), U3.12 (+), U4.12 (+), U5.1 (GND)
LCD_DC: J10.4, U1.2 (PC13), U2.5
LCD_MISO: J10.7, J11.1
LCD_MOSI: J10.6, U1.57 (PB5), U2.6
LCD_RESET: J10.2, U1.3 (PC14), U2.4
LCD_SCK: J10.3, U1.55 (PB3), U2.7
L_ENC_BTN: C9.1, SW1.S1, U1.43 (PA10)
L_ENC_DN: SW1.B, U1.59 (PB7)
L_ENC_UP: SW1.A, U1.58 (PB6)
MIDI_OUT: U1.52 (PC11), U3.8, U3.9 (-)
NRST: C8.2, SW3.1, U1.7 (NRST)
unnamed: C2.1, U1.5 (PH0), Y1.2
unnamed: C3.1, U1.6 (PH1), Y1.1
unnamed: C5.1, U1.30 (VCAP_1)
unnamed: R1.1, R2.1, R7.2, U3.6 (-)
unnamed: R3.1, R4.1, R8.2, U3.13 (-)
unnamed: R5.1, R6.1, R9.2, U3.2 (-)
unnamed: R10.2, U4.8, U4.9 (-)
unnamed: R11.2, U4.6 (-), U4.7
unnamed: R12.2, U4.1, U4.2 (-)
unnamed: U4.13 (-), U4.14
R_ENC_BTN: C10.1, SW2.S1, U1.34 (PB13)
R_ENC_DN: SW2.B, U1.38 (PC7)
R_ENC_UP: SW2.A, U1.37 (PC6)
SWCLK: J1.4, U1.49 (PA14)
SWDIO: J1.3, U1.46 (PA13)
VCC: C11.1, C12.1, D1.1 (K), U4.4 (V+), U5.3 (VI)
VEE: C13.2, D2.2 (A), R1.2, R3.2, R5.2, U4.11 (V-)

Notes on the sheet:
Pins 19, 32, 48, 64 ground capacitors
CV Input Scaling
Power Sections
5 = CS

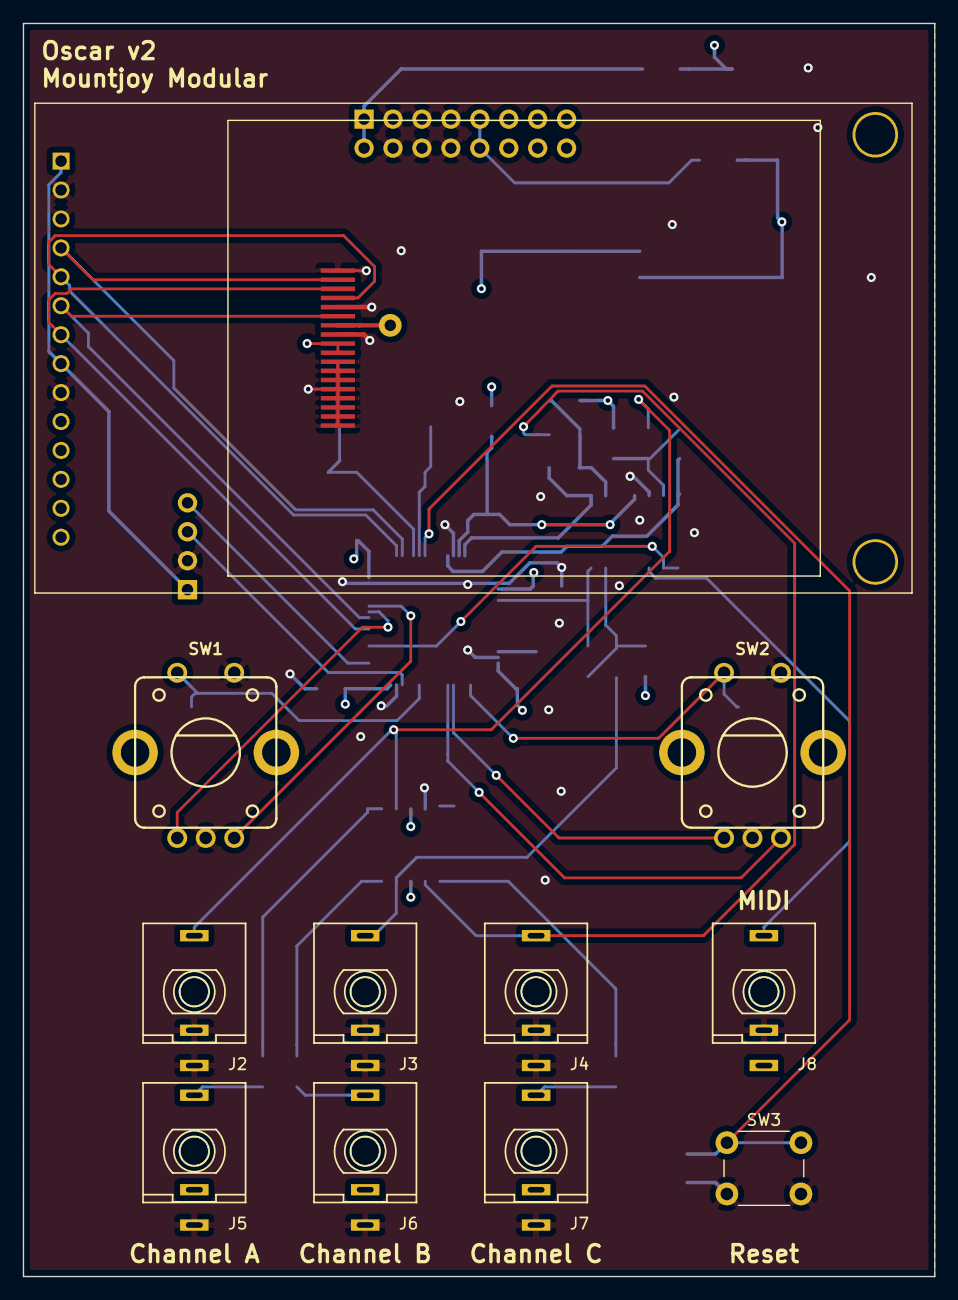
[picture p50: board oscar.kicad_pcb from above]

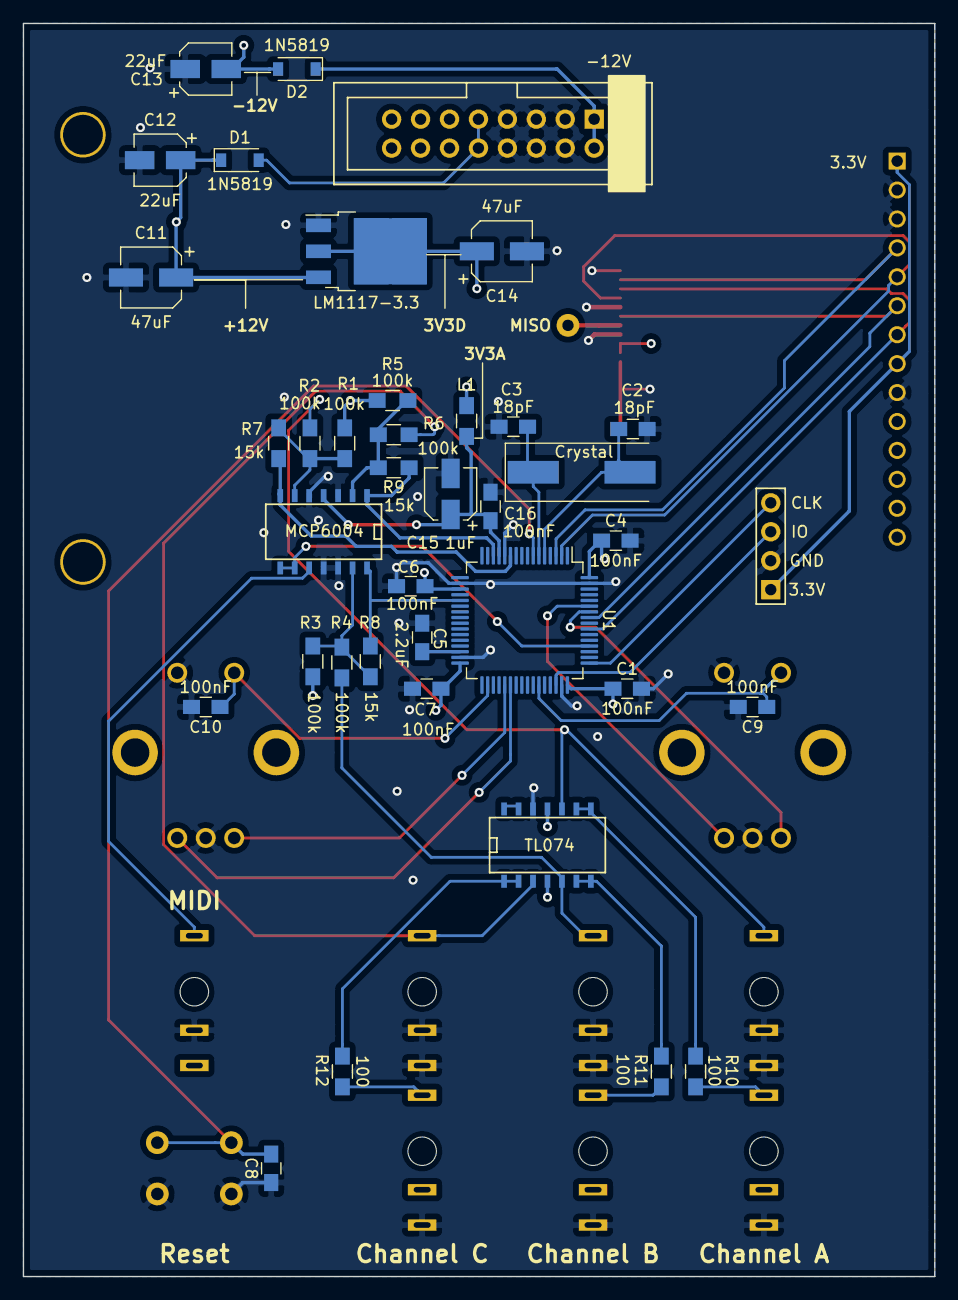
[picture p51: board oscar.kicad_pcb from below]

Board: 4 copper layers, 80.0 x 110.0 mm, 51 parts (38 on the bottom side), 42 nets.

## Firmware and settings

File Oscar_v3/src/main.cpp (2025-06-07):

#include <MidiEvents.h>
#include "initialisation.h"
#include "configManager.h"
#include "ui.h"
#include "lcd.h"
#include "fft.h"
#include "osc.h"
#include "tuner.h"
#include "USB.h"

volatile uint32_t SysTickVal = 0;


extern "C" {
	#include "interrupts.h"
}

UI ui;
Osc osc;
FFT fft;
Tuner tuner;

Config config{&ui.configSaver, &osc.configSaver, &fft.configSaver, &tuner.configSaver};		// Construct config handler with list of configSavers


int main(void)
{
	InitHardware();
	lcd.Init();								// Initialize ILI9341 LCD

	// check if resetting config by holding menu button while resetting
	if (ui.btnMenu.pin.IsHigh()) {			// If button is NOT pressed reload config
		config.RestoreConfig();				// Restore calibration settings from flash memory
	}

	InitSampleAcquisition();
	ui.ResetMode();
	osc.CalcZeroSize();
	usb.Init(false);
	//InitWatchdog();

	while (1) {
		//ResetWatchdog();					// Reloads watchdog counter to prevent hardware reset
		ui.handleEncoders();
		config.SaveConfig();				// Save any scheduled changes
		usb.cdc.ProcessCommand();			// Check for incoming CDC commands


		if (ui.menuMode != UI::MenuMode::off) {

		} else if (ui.cfg.displayMode == DispMode::Oscilloscope) {
			osc.OscRun();
		} else if (ui.cfg.displayMode == DispMode::Tuner) {
			tuner.Run();
		} else if (ui.cfg.displayMode == DispMode::Fourier || ui.cfg.displayMode == DispMode::Waterfall) {
			fft.Run();
		} else if (ui.cfg.displayMode == DispMode::MIDI) {
			midiEvents.ProcessMidi();
		}

	}
}

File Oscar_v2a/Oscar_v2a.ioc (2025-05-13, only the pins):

Mcu.UserName=STM32F446RETx
PA11.Signal=USB_OTG_FS_DM
PA12.Signal=USB_OTG_FS_DP
PB3.Signal=SPI3_SCK
PB5.Signal=SPI3_MOSI
PH0-OSC_IN.Signal=RCC_OSC_IN
PH1-OSC_OUT.Signal=RCC_OSC_OUT

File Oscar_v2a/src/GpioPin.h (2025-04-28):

#pragma once

class Btn;
extern volatile uint32_t SysTickVal;

class GpioPin {
	friend Btn;

public:
	enum class Type {Input, InputPullup, InputPulldown, Output, AlternateFunction, AlternateFunctionPullUp, AlternateFunctionPullDown};
	enum class DriveStrength {Low, Medium, High, VeryHigh};
	enum class OutputType {PushPull, OpenDrain};


	GpioPin(GPIO_TypeDef* port, uint32_t pin, Type pinType, uint32_t alternateFunction = 0, DriveStrength driveStrength = DriveStrength::Low, OutputType outputType = OutputType::PushPull) :
		port(port), pin(pin), pinType(pinType)
	{
		Init(port, pin, pinType, alternateFunction, driveStrength);		// Init function is static so can be called without instantiating object
	}


	static void Init(GPIO_TypeDef* port, const uint32_t pin, const Type pinType, const uint32_t alternateFunction = 0, const DriveStrength driveStrength = DriveStrength::Low, OutputType outputType = OutputType::PushPull)
	{
		// maths to calculate RCC clock to enable
#if defined(STM32H723xx)
	const uint32_t portPos = ((uint32_t)port - GPIOA_BASE) >> 10;
	RCC->AHB4ENR |= (1 << portPos);
#elif defined(STM32H7B0xx)
	const uint32_t portPos = ((uint32_t)port - SRD_AHB4PERIPH_BASE) >> 10;
	RCC->AHB4ENR |= (1 << portPos);
#elif defined(STM32H563xx)
	const uint32_t portPos = ((uint32_t)port - AHB2PERIPH_BASE_NS) >> 10;
	RCC->AHB2ENR |= (1 << portPos);
#elif defined(STM32G473xx)
	const uint32_t portPos = ((uint32_t)port - AHB2PERIPH_BASE) >> 10;
	RCC->AHB2ENR |= (1 << portPos);
#elif defined(STM32F446xx) or defined(STM32F405xx)
	const uint32_t portPos = ((uint32_t)port - AHB1PERIPH_BASE) >> 10;
	RCC->AHB1ENR |= (1 << portPos);
#endif


		// 00: Input, 01: Output, 10: Alternate function, 11: Analog (reset state)
		if (pinType == Type::Input || pinType == Type::InputPullup || pinType == Type::InputPulldown) {
			port->MODER &= ~(0b11 << (pin * 2));

		} else if (pinType == Type::Output) {
			port->MODER |=  (0b01 << (pin * 2));
			port->MODER &= ~(0b10 << (pin * 2));

		} if (pinType == Type::AlternateFunction || pinType == Type::AlternateFunctionPullUp || pinType == Type::AlternateFunctionPullDown) {
			port->MODER |=  (0b10 << (pin * 2));
			port->MODER &= ~(0b01 << (pin * 2));
			if (pin < 8) {
				port->AFR[0] |= alternateFunction << (pin * 4);
			} else {
				port->AFR[1] |= alternateFunction << ((pin - 8) * 4);
			}
		}

		if (pinType == Type::InputPullup || pinType == Type::AlternateFunctionPullUp) {
			port->PUPDR |= (0b1 << (pin * 2));
		}
		if (pinType == Type::InputPulldown || pinType == Type::AlternateFunctionPullDown) {
			port->PUPDR |= (0b10 << (pin * 2));
		}


		port->OSPEEDR |= static_cast<uint32_t>(driveStrength) << (pin * 2);

		if (outputType == OutputType::OpenDrain) {
			port->OTYPER |= 1 << pin;
		}
	}


	static bool IsHigh(GPIO_TypeDef* port, const uint32_t pin) {
		return (port->IDR & (1 << pin));
	}

	bool IsHigh() {
		return (port->IDR & (1 << pin));
	}

	static bool IsLow(GPIO_TypeDef* port, const uint32_t pin) {
		return ((port->IDR & (1 << pin)) == 0);
	}

	bool IsLow() {
		return ((port->IDR & (1 << pin)) == 0);
	}

	static void SetHigh(GPIO_TypeDef* port, const uint32_t pin) {
		port->ODR |= (1 << pin);
	}

	void SetHigh() {
		port->ODR |= (1 << pin);
	}

	static void SetLow(GPIO_TypeDef* port, const uint32_t pin) {
		port->ODR &= ~(1 << pin);
	}

	void SetLow() {
		port->ODR &= ~(1 << pin);
	}

	void Set(bool high) {
		if (high) {
			port->ODR |= (1 << pin);
		} else {
			port->ODR &= ~(1 << pin);
		}
	}

private:
	GPIO_TypeDef* port;
	uint32_t pin;
	Type pinType;
};


// Struct to manage buttons with debounce and GPIO management
struct Btn {
	GpioPin pin;
	uint32_t down = 0;			// set to zero if button has been pressed and is subsequently released
	uint32_t up = 0;			// Set to last release time
	bool longPressed = false;

	// Debounce button press mechanism
	bool Pressed() {
		// Has been pressed and now released
		if (!ButtonDown() && down && SysTickVal > up + 200) {		// button not pressed
			down = 0;
			up = SysTickVal;
			if (longPressed) {
				longPressed = false;
				return false;
			}
			return true;
		}

		if (ButtonDown() && down == 0 && SysTickVal > up + 200) {	// button pressed
			down = SysTickVal;
			up = 0;
		}
		return false;
	}

	bool LongPress() {
		if (ButtonDown() && !longPressed && down && SysTickVal > down + 1500) {
			longPressed = true;
			return true;
		}
		return false;
	}

	bool ButtonDown() {
		return pin.pinType == GpioPin::Type::InputPullup ? pin.IsLow() : pin.IsHigh();
	}
};

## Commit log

2019-04-18 Switched from ADC2 to ADC1
2019-04-20 Updates to LCD Class
    [_saved_oscar.sch, oscar.sch]
2019-04-20 draw character uses DMA/SPI
2019-04-24 Added fourier transform test scripts
    [output.xls]
2019-04-25 Added FFT
    [output.xls]
2019-04-26 FFT optimisations
    [output.xls]
2019-04-27 Fixes to trigger mode stability; first draft of FFT from samples
    [main.cpp]
2019-04-28 FFT working on ADC data
    [output.xls]
2019-04-29 Added switching between FFT and oscilloscope
2019-05-01 Fixed issues in oscilloscode triggering at high speeds and cleaned up FFT draw code
    [main.cpp]
2019-05-02 Code cleanup; Encoders with debouncing
    [output.xls]
2019-05-04 Refactor including moving fft to new class; speed up sample capture
    [output.xls]
2019-05-10 added calibration and voltage scaling for oscilloscope
    Moved various functions to UI class
    Added frequency calculation on oscilloscope
2019-05-10 Show frequency on oscilloscpe and optimise string drawing
    [oscar.sch]
2019-05-14 Waterfall plot works with frame buffers
2019-05-18 Error handling in FFT; Reworked menu operations
    [fft.cpp, lcd.h, main.cpp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]
2019-06-18 Added software debouncing for encoders and buttons; more work on menu
2019-06-27 Added third channel
    [oscar.sch]
2019-07-12 Updated Encoders to use Timers
2019-07-12 Further hardware abstraction and moved interrupts
2019-07-19 First draft of PCB layout
    [oscar.kicad_pcb, oscar.sch]
2019-07-20 Better scaling for horizontal zoom; 4 layer board updates
    [oscar.kicad_pcb, oscar.sch]
2019-07-22 MIDI uses ring buffer instead of queu and added clock
    [oscar.kicad_pcb, oscar.sch]
2019-07-23 Added LCD Solder pads
    [oscar.kicad_pcb, oscar.sch]
2019-07-23 increased size of power traces
    [oscar.kicad_pcb]
2019-07-28 v1 PCB; added zero crossing count config to Circular mode; refactored variables into objects
    [Oscar_Pins.xlsx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]
2019-08-17 Created LCD daughterboard
    [lcd_Daughterboard-B_Cu.gbr, lcd_Daughterboard-B_Mask.gbr, lcd_Daughterboard-B_Paste.gbr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]
2019-09-04 PCB Updated to incorporate LCD daughterboard
    [lcd_Daughterboard.sch, oscar.kicad_pcb, oscar.sch]
2019-09-06 Added panel PCB
    [oscar.kicad_pcb, oscar_panel.kicad_pcb]
2019-09-07 Updates to panel PCB
    [oscar_panel.kicad_pcb]
2019-09-08 updated codebase
    [oscar_panel.kicad_pcb]
2019-11-09 Reorganised and relocated reposistory
    [Oscar_Pins.xlsx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]
2020-02-08 Increased oscillator max voltage from 8V to 12V; fixes to FFT menu (allows channel select in config)
    [oscar.kicad_pcb, oscar.sch, output.xls]
2020-02-09 Reversed direction of zoom encoders; added option to vertically scale overlay in FFT
    Also increased maximum oscillator window time to ~2s
    [ui.cpp]
2020-06-03 FFT Mode channel select reverse direction fixed; converted project to CubeIDE
    [ui.cpp]
2022-03-31 Updates to Kicad 6
2023-03-13 Testing sample timer resolution changes
2023-03-13 Increased sample capture resolution by reducing speed of prescaler
2023-03-14 Cleaned unused and old driver files
2023-03-14 Fixed bug in oscillator drawing function
    [osc.cpp]
2023-03-14 Fixed bug in harmonicFreq() function incorrectly truncating large frequencies
    [fft.cpp, lcd.cpp, lcd.h]
2023-03-15 Fixed bug using right encoder button in mode with no menu
    [ui.cpp]
2023-03-15 Reworked encoder button handling to avoid using interrupts and improve debouncing
    [initialisation.cpp, main.cpp, ui.cpp]
2023-03-15 Fixed bug drawing fft overlay offset by 1
    [fft.cpp]
2023-03-17 Fixed buffer overflow in osc;
    const updates and space saving to lcd class
    fft class uses constexpr sine look up table
    [fft.cpp, lcd.cpp, lcd.h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]
2023-03-17 Added readme and graphics
    [oscar.kicad_pcb, oscar.kicad_sch]
2023-03-17 Corrections to ReEadme and ioc file
    [Oscar446.ioc, initialisation.cpp]
2023-03-22 Update notes in schematic
    [oscar.kicad_sch]
2023-04-01 Allow pitch detection where multiple zero crossings in cycle
2023-04-03 Added sample capture to tuner FFT mode
2023-04-07 Improved accuracy of FFT tuner at higher frequencies
    Display note name and error in cents
    [tuner.cpp, ui.cpp]
2023-04-11 Fine tuning tuner issues
    [tuner.cpp]
2023-06-11 Added potential fix for overflow bug in FFT
    [fft.cpp]
2023-07-09 Added trace overlay to tuner mode
2024-07-12 Fixed inverted tuner wave overlay
    [lcd.h, tuner.cpp]
2024-12-16 Fixed bug with MIDI off events being lost; added reverse encoder option
    [ui.cpp]
2025-03-31 Started creating v2 hardware; added construction images
    [lcd_Daughterboard.kicad_pcb, lcd_Daughterboard.kicad_sch, lcd_Daughterboard.sch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]
2025-04-03 Routing of component board
    [lcd_Daughterboard.kicad_pcb, lcd_Daughterboard.kicad_sch, lcd_Daughterboard.sch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]
2025-04-03 Folder reorganisation
    [lcd_Daughterboard-B_Cu.gbr, lcd_Daughterboard-B_Mask.gbr, lcd_Daughterboard-B_Paste.gbr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]
2025-04-03 PCB Layout
    [oscar_components.kicad_pcb, oscar_components.kicad_sch]
2025-04-05 Started working on panel
    [lcd_Daughterboard.kicad_pcb, oscar_components.kicad_pcb, oscar_components.kicad_sch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]
2025-04-06 Control Layout change
    [lcd_Daughterboard.kicad_pcb, oscar_components.kicad_pcb, oscar_components.kicad_sch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]
2025-04-07 Started adding JLC part numbers; changed optocoupler to H11L1
    [BOM-oscar_components.csv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]
2025-04-12 More layout
    [lcd_Daughterboard.kicad_pcb, lcd_Daughterboard.step, oscar_components.kicad_pcb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]
2025-04-13 Started updating firmware to v2a
    [oscar_panel.kicad_pcb]
2025-04-14 V3 production files submitted to JLC
    [BOM-oscar_components.csv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]
2025-04-27 USB working
    [oscar_components.kicad_sch]
2025-04-27 Schematic annotation
    [oscar_components.kicad_sch]
2025-04-28 Buttons and LEDs working correctly
    [GpioPin.h, ui.cpp]
2025-05-12 Implemented channel selection buttons
2025-05-13 Selectively update oscilloscope voltage
2025-05-16 New 3.1 daughterboard layout
    [lcd_Daughterboard-B_Cu.gbr, lcd_Daughterboard-B_Mask.gbr, lcd_Daughterboard-B_Silkscreen.gbr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]
2025-05-19 Updated LED resistor values
    [BOM-oscar_components.csv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]
2025-05-23 Fixes to oscilloscope draw in block mode
    [CDCHandler.cpp, GpioPin.h, USB.cpp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]
2025-05-24 Fixes to oscilloscope draw routine
    [osc.cpp]
2025-06-03 Reverting oscilloscope performance testing
    [osc.cpp, osc.h]
2025-06-03 Fixed text centering in tuner mode
    [fft.cpp, lcd.cpp, lcd.h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]
2025-06-06 USB bootloader working
    [oscar_components.kicad_sch, oscar_panel.kicad_pcb]
2025-06-07 UI fixes; minor tweaks to v3.2 LCD daughterboard
    [lcd_Daughterboard-B_Cu.gbr, lcd_Daughterboard-B_Mask.gbr, lcd_Daughterboard-B_Silkscreen.gbr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]
2025-06-11 Fixes to oscilloscope frequency estimation
    [initialisation.cpp, osc.cpp, osc.h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]
2025-06-13 Uploaded zipped gerbers
2025-06-14 Work on Build Guide; Clean up old folders
    [BOM-oscar_components.csv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]
2025-06-23 Updates to build guide and readme
    [oscar_components.kicad_sch]
2025-06-24 Switch off channel button LEDs in MIDI mode
2025-06-26 Updated sample time defaults on oscilloscope
    + add clear config command to serial console
2025-07-25 Increased size of regulator heat sink vias
    [oscar_components-CuBottom.gbr, oscar_components-CuIn1.gbr, oscar_components-CuIn2.gbr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]
